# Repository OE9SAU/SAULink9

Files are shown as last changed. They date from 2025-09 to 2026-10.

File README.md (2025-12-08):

# SAULink9 - DIY interface for your analog radio

SAULink9 is a DIY project that bridges analog radios with the SVXLink Austria network or any other SVXLink networks like FM-FUNKNETZ.
It’s designed for amateur radio operators who want to flexibly connect their analog repeaters or other analog devices.

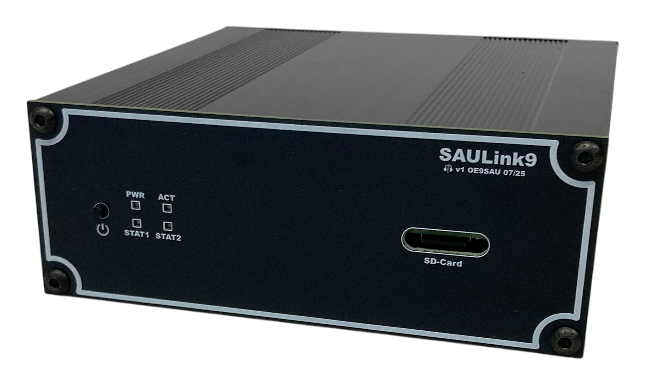
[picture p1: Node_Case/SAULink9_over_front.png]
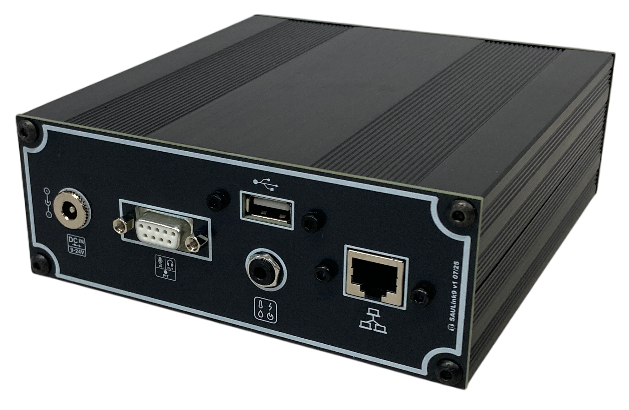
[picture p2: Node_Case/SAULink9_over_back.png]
 

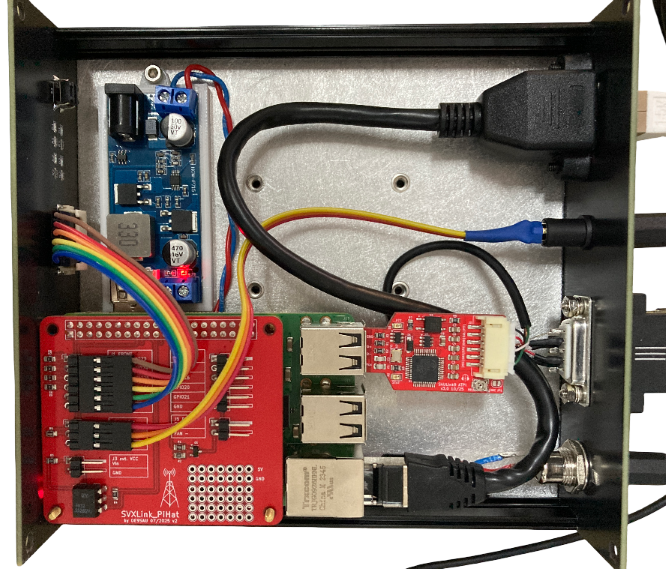
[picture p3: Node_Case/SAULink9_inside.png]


## Highlights

🔹 Base system: cost-effective Raspberry Pi 3B+

🔹 Wide-range power input (9–24 VDC) via integrated DC-DC converter

🔹[Front panel](https://github.com/OE9SAU/SAULink9/tree/main/Node_Case)
 * Start/Shutdown button
 * Status LEDs for system monitoring
 * Easy SD card front access for quick updates and maintenance
   
🔹 All key connections located on the [Back panel](https://github.com/OE9SAU/SAULink9/tree/main/Node_Case) for neat cabling
 * DC-In
 * TRX connection
 * 1-Wire temperature sensor to monitor TRX temperature
 * USB
 * Network

🔹 [PiHat for Rpi3B+](https://github.com/OE9SAU/SAULink9/tree/main/Rpi_Hat)
  * front panel connection point
  * Convenient access to 4 GPIOs (for relays or other circuits)
  * FET-controlled fan output
  * Dedicated 1-Wire port
  * External voltage detection via optocoupler
  * Extra DIY prototyping space

🔹[ATPI USB-Soundinterface with CM108](https://github.com/OE9SAU/SAULink9/tree/main/ATPI)
    
🔹 Compatible with mostly any analog TRX devices

🔹 DIY & flexible – easy to set up and adapt to your needs

🔹 Direct connection to the [SVXLink Austria Reflektor OE9XFP](http://oe9xvi.dyndns.org:46197)

🔹 Built-in EchoLink integration

🔹 Works seamlessly with other SVXLink networks such as FM-FUNKNETZ

🔹 Open source & community-driven – can be further developed together

#### SAULink9 extends the range and flexibility of your analog radios and makes getting started with the SVXLink project particularly easy.

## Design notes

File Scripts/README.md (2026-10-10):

<p align="center">
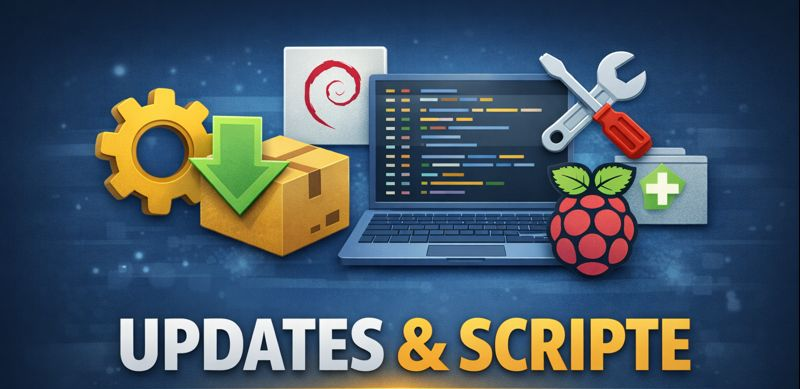
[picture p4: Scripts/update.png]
  
</p>

# Erweiterung eSM Server Monitor
Das eSM Dashboard ist im SAULink Dashboard mit einem Klick auf **Hardware Info** erreichbar.
Das Script im Ordner /eSM erweitert das bestehende eSM Dashboard um einen Temperaturgraphen zur Darstellung der CPU-Temperatur im zeitlichen Verlauf (60 Minuten).
In Verbindung mit der **FanControl** lässt sich damit gut beobachten, wie sich die CPU-Temperatur entwickelt und wann die temperaturgesteuerte Lüftersteuerung ein- bzw. ausschaltet.

## Installation
```
sudo wget -qO install-tempgraph.sh \
https://raw.githubusercontent.com/OE9SAU/SAULink9/main/Scripts/eSM/install-tempgraph.sh && \
sudo chmod +x install-tempgraph.sh && \
sudo ./install-tempgraph.sh
```

# FanControl

Temperaturgesteuerte Lüftersteuerung für SAULink auf Basis von **pigpio**.
Die FanControl überwacht die CPU-Temperatur des Raspberry Pi und steuert den angeschlossenen Lüfter automatisch anhand der festgelegten Temperaturschwellen.
Zusammen mit dem Temperaturgraphen im eSM Dashboard lässt sich das Verhalten der Lüftersteuerung einfach überwachen und nachvollziehen.

Für den Lüftereinbau muss der Gehäusedeckel modifiziert werden.

Verwendeter Lüfter: https://www.amazon.de/dp/B0DKJP347L?ref_=ppx_hzsearch_conn_dt_b_fed_asin_title_2

## Funktionen

- GPIO 18 schaltet einen Lüfter über den MosFet auf dem Rpi_Hat
- Lüfter EIN ab 65 °C
- Lüfter AUS unter 50 °C
- Hysterese verhindert Flattern
- Startet automatisch beim Booten über systemd

## Installation
```
sudo wget -qO install-fancontrol.sh \
https://raw.githubusercontent.com/OE9SAU/SAULink9/main/Scripts/fancontrol/install-fancontrol.sh && \
sudo chmod +x install-fancontrol.sh && \
sudo ./install-fancontrol.sh
```

## Standardwerte

| Parameter | Wert |
|---|---|
| GPIO | 18 |
| Einschalten | 65 °C |
| Ausschalten | 50 °C |
| Prüfintervall | 5 Sekunden |

## Dienst

Status anzeigen:

```
systemctl status fancontrol
```

Neustarten:

```
sudo systemctl restart fancontrol
```

Stoppen:

```
sudo systemctl stop fancontrol
```
---

# Update SvxLink Dashboard Ver 2.1
### Verbesserte aktualisierung der SVXReflector Activity Tabelle

-Sortierung verbessert

-Datum wird mitangezeigt

-Anzeige auf 23 Einträge erweitert

# Script herunterladen
```
wget -O /tmp/lh_update.sh \
https://raw.githubusercontent.com/OE9SAU/SAULink9/refs/heads/main/Scripts/lh_update.sh
```

# Rechte setzen
```
sudo chmod +x /tmp/lh_update.sh
```
# Script ausführen
```
sudo /tmp/lh_update.sh
```
---
# Update der Status LEDs im Frontpanel inkl.Watchdog Funktion, Schaltung unter SAULink9/Watchdog

v2.4: Statusprüfung angepasst, erkannte Authentication OK-Verbindung UP bleibt, bis tatsächlich eine Trennung/Fehlermeldung kommt

Script dient der Anpassung der Statusanzeige von SVXLink-Dienst und der Reflektor-Verbindungen über die beiden roten GPIO-LEDs im Frontpanel inkl. GPIO für Watchdog

### Statusanzeige – SVXLink (STAT LED 1 bestehend)

|SVXLink | LED-Verhalten |
|---|---|
| Dienst läuft nicht | Dauer-AN |
| Dienst läuft | Blinkend (0,5 s) |

### Statusanzeige – Reflektor (STAT LED 2 Neu)

| Reflektor Verbindung | LED-Verhalten |
|---|---|
| UP | Blinkend (0,5 s) |
| CONNECTING | Langsam blinkend |
| DOWN / ERROR | Dauer-AN |

## Installation:
```
sudo systemctl stop svxlink_service_led.service
```
### Script von GitHub laden:
```
sudo cp -a /usr/local/bin/svxlink_service_led.py \
/usr/local/bin/svxlink_service_led.py.bak 2>/dev/null || true \
&& sudo curl -fsSL https://raw.githubusercontent.com/OE9SAU/SAULink9/refs/heads/main/Scripts/svxlink_service_led.py \
-o /usr/local/bin/svxlink_service_led.py \
&& sudo chmod 755 /usr/local/bin/svxlink_service_led.py
```
### Service aktivieren:
```
sudo systemctl daemon-reload && \
sudo systemctl enable svxlink_service_led.service && \
sudo systemctl start svxlink_service_led.service
```
### Service Status:
```
sudo systemctl status svxlink_service_led.service
```
---
# Rpi System-Update:

Script führt ein normales Systemupdate (apt update + apt upgrade) durch und stellt anschließend sicher, 

dass der Apache Webserver wieder mit PrivateTmp=false läuft. Was für die Funktion von DTMF und Co benötigt wird!

## Voraussetzung: 

SAULink9 mit Debian 12 "Bookworm"

OS und Release Version anzeigen
```
. /etc/os-release && echo "Debian $VERSION_ID.$(cut -d. -f2 /etc/debian_version) ($VERSION_CODENAME)"
````

# Funktionsweise:
1. Systemupdate ausführen
2. systemd-Override für apache2 prüfen/erstellen:
/etc/systemd/system/apache2.service.d/override.conf
3. systemd neu laden
4. Apache neu starten
5. Status von PrivateTmp anzeigen

# Verwendung:
Script von GitHub laden
````
sudo curl -fsSL https://raw.githubusercontent.com/OE9SAU/SAULink9/refs/heads/main/Scripts/update-system.sh \
  -o /usr/local/sbin/update-system.sh \
  && sudo chmod 755 /usr/local/sbin/update-system.sh
````
Script ausführen
````
sudo update-system.sh
````
# Ablage:
/usr/local/sbin/update-system.sh

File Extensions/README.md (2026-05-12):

# SAULink9 Extensions @ in progess

SAULink9 is a DIY project that bridges analog radios with the SVXLink Austria network or any other SVXLink networks like FM-FUNKNETZ.
It’s designed for amateur radio operators who want to flexibly connect their analog repeaters or other analog devices.

 

## WATCHDOG

can be used to monitor the SAULink9 SVX-Service 

## TAIT-PLEXER

use two Tait Device for Repeater with and without SAULink9

## AP

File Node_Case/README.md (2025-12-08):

# SAULink9 Node Case

Front panel, back panel and base plate for aluminium housing (see partlist), fit all part´s you need to build up a SAULink9 Node for SVX- and EchoLink use.

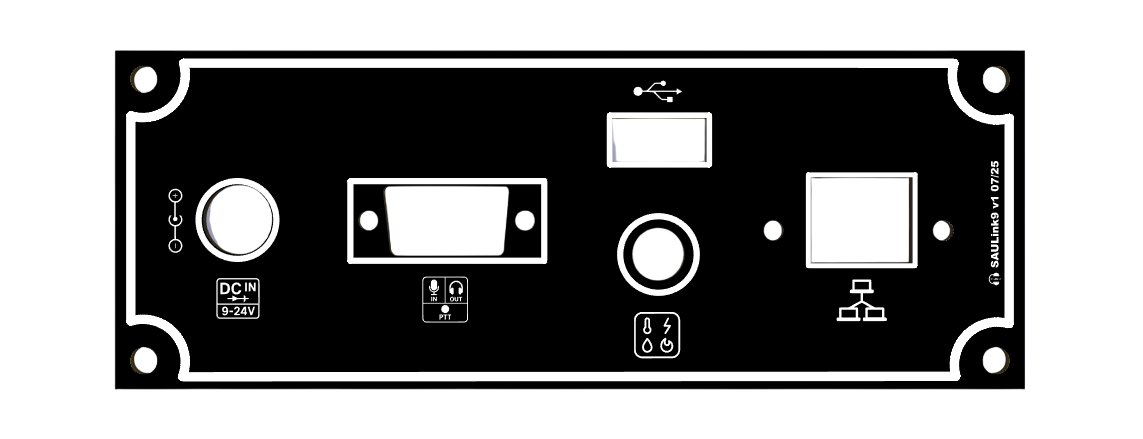
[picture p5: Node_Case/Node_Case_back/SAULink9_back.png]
Caseoverfront

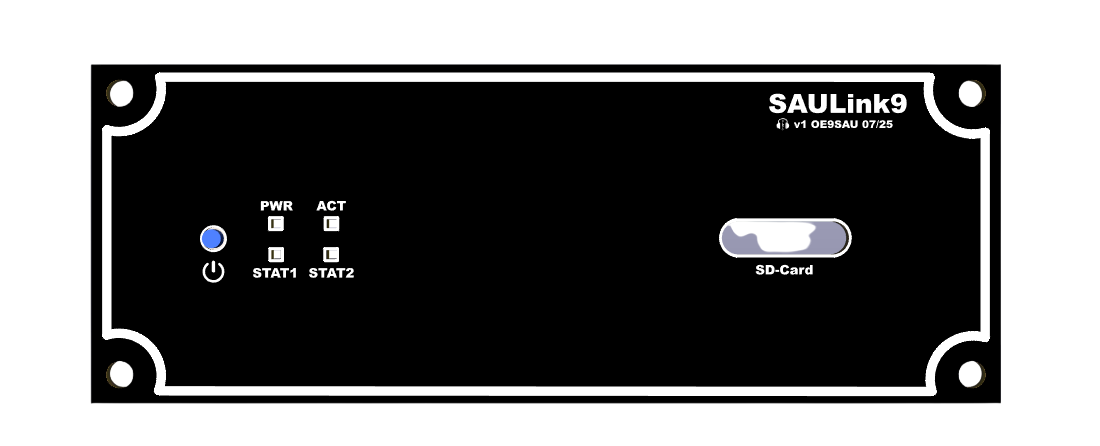
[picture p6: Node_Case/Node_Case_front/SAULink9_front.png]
Caseoverback


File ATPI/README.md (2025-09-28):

# SAULink9 ATPI

This project based on a CM108 soundchip provides an Audio and PTT (Push-to-Talk) interface to connect your analog radio.
Mainly it acts as a bridge between SAULink9 nodes and external radio hardware for any SVXLink network or any other applications.

### Features:

* Audio input/output

  * 100K potentiometer enables you to make fine tuned adjustments to the audio going in to the CM108 (GM340 etc)
    
  * Output audio levels are generally set in whichever software you're using with the ATPI

* PTT line control to GND thru optocoupler

* COS (Carrier on Squelch) input blocked by diode

* Easy integration/replacement into existing SAULink9 / SVXLink setups

* Customizing the device name with integrated EEPROM

* works with VARA

### Versions
v3.0: like v2.0 with EEPROM for Device name informations

v2.0: shorter version without 1:1 transformer

v1.1: like v1.0 footprint D1 changed to SOD-123

v1.0: with 1:1 transformer -> Audio level to low

### Note
all versions must be ordered in 1.2mm PCB thickness

all versions must be glued together with the empty board version, ordered as well with 1.2mm PCB thicknes, to achieve the USB connector thickness of around 2.5mm

v3.0
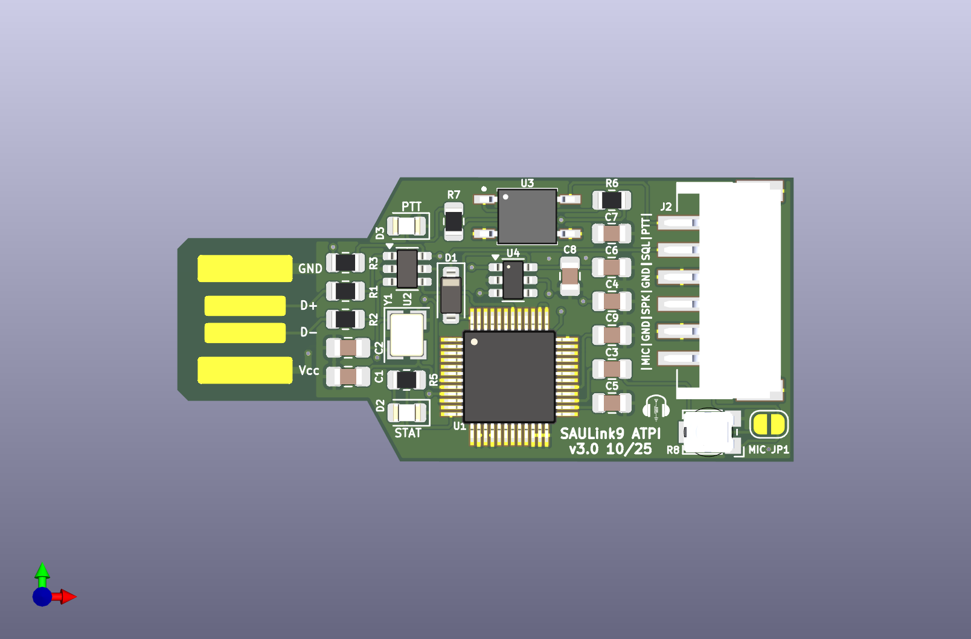
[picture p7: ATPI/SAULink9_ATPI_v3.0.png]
ATPI


v2.0
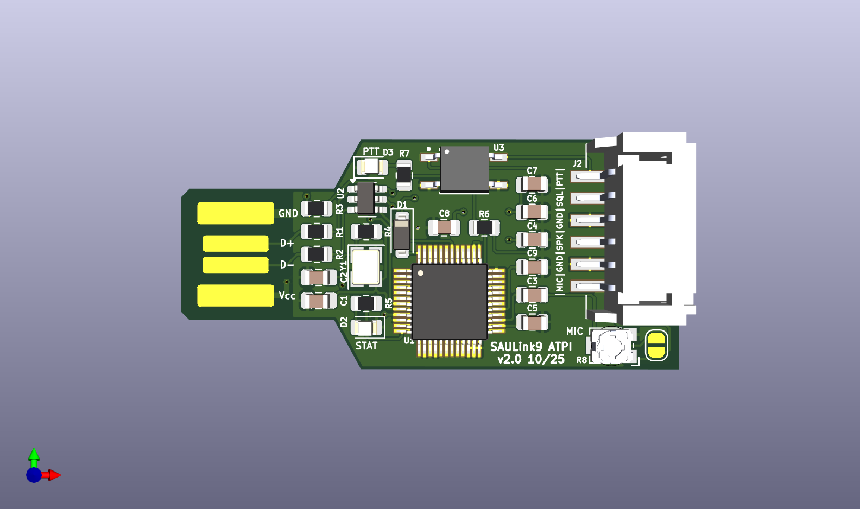
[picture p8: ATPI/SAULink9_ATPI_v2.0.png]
ATPI


v1.1
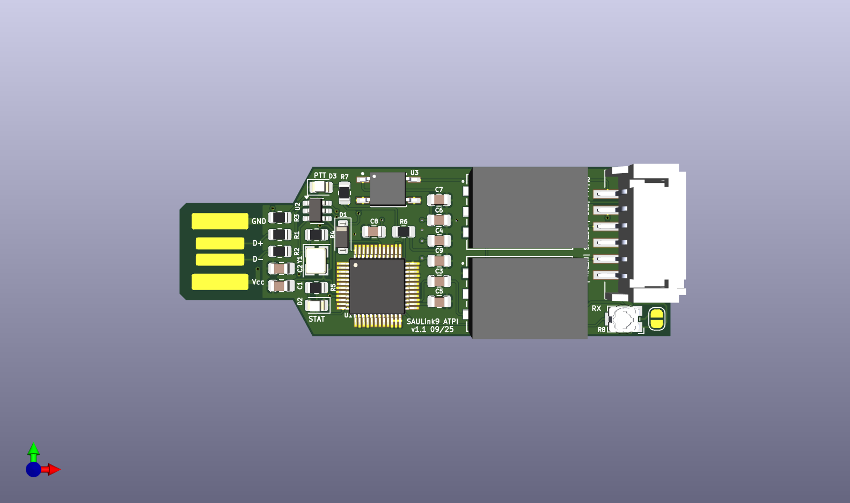
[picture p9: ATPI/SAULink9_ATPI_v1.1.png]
ATPI


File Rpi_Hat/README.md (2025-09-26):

# SAULink9 RPiHat

PiHat for Rpi3B+, give space to some GPIOs and connection point to the SAULink9 front panel

## Highlights
  * front panel connection point
  * Convenient access to 4 GPIOs (for relays or other circuits)
  * FET-controlled fan output
  * Dedicated 1-Wire port
  * External voltage detection via optocoupler
  * Extra DIY prototyping space

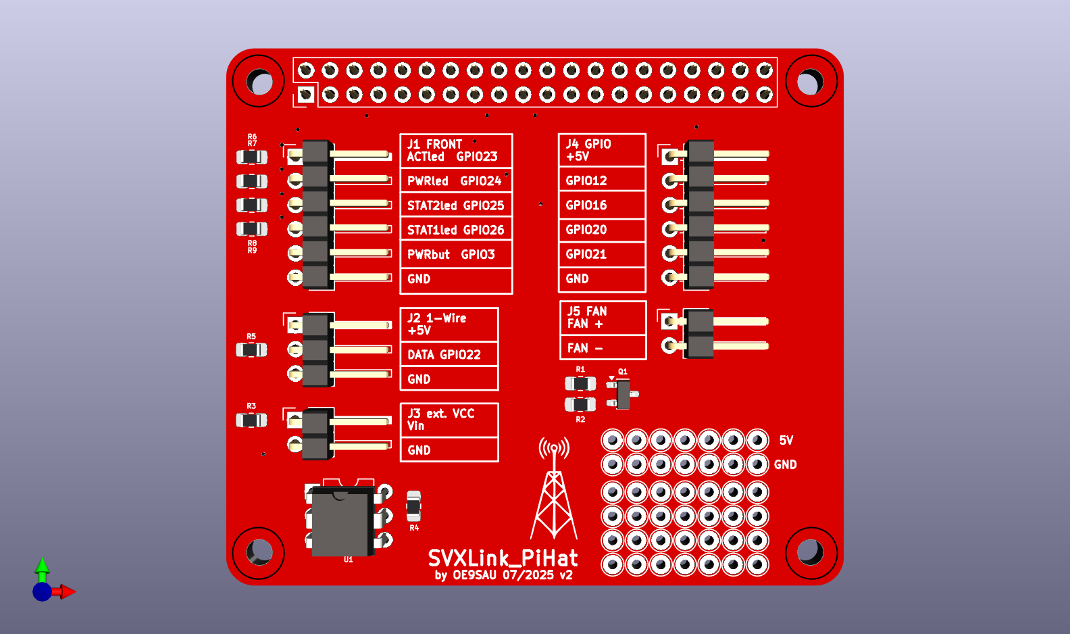
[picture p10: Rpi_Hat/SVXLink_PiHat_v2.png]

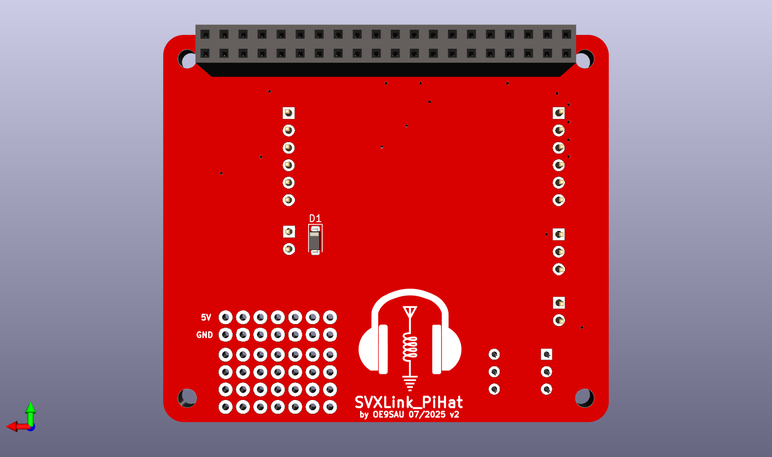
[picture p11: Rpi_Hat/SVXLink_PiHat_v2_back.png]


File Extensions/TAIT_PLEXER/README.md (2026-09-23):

## SAULink9 TAIT-PLEXER

In case of problems like no reflector connection or SAULink9 down, SAULink9 Watchdog (Extensions/WATCHDOG) sets the TAIT-PLEXER 

to LOW and both TAIT device are acting as local fm-repeater

v1.0 Testdesign

v1.1 changed pinout v1.0 by handwiring for current TAIT pinout config

v2.0 changed pinout for current TAIT pinout config

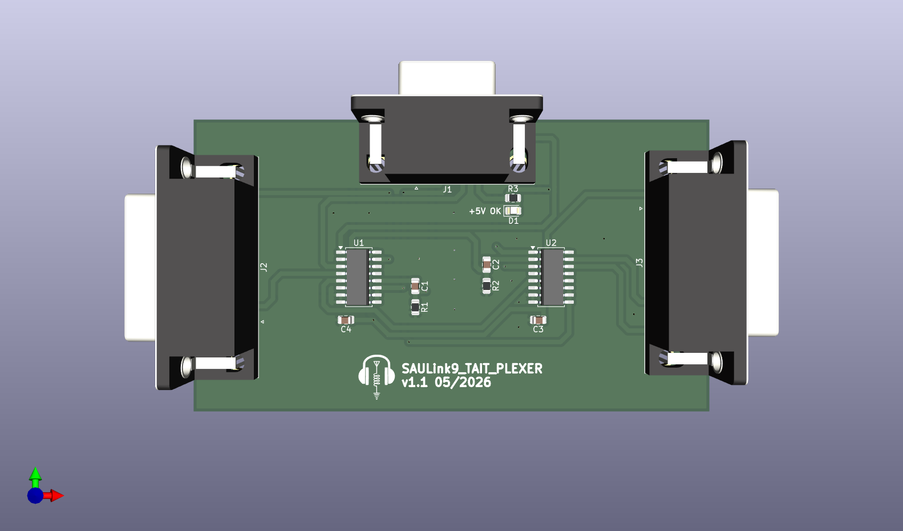
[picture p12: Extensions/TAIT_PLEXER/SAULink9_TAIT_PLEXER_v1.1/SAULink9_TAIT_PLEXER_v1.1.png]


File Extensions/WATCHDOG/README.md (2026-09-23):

## SAULink9 Watchdog v1.1

The watchdog timer is repeatedly started by a trigger. If the trigger is missing, the timer with 33sec runs down and then the output switch to ...

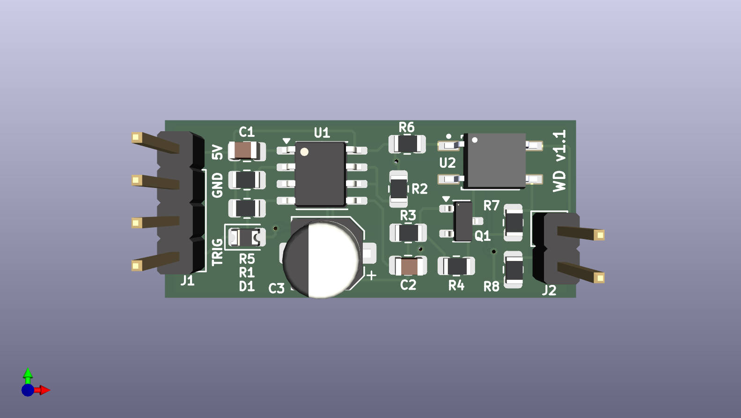
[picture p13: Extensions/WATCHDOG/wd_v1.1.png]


v1.1: Add R7 & R8 to define PULLUP or PULLDOWN, without R7 & R8 acting potentialfree

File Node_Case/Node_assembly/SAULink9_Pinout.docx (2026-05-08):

1-Wire jack socket

1 | GND
2 | 5V
3 | Data
4 | ------

1-Wire jack plug

5V

Data

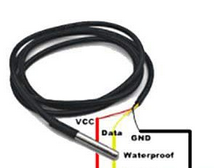
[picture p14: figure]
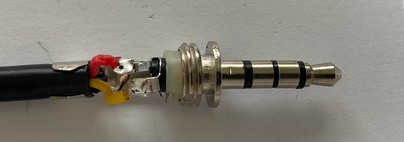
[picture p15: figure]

Sub-D 9pol (Blick von hinten auf die Buchse)

Sub-D | Code | | Sub-D Kabel zu TRX
1 | shield | GND | red
2 | black | PTT, Aktiv LOW | green
4 | red | CTCSS/SQL | lila
7 | white | Output = TX Audio | white
9 | green | Input = RX Audio | black

Amazon Soundinterface

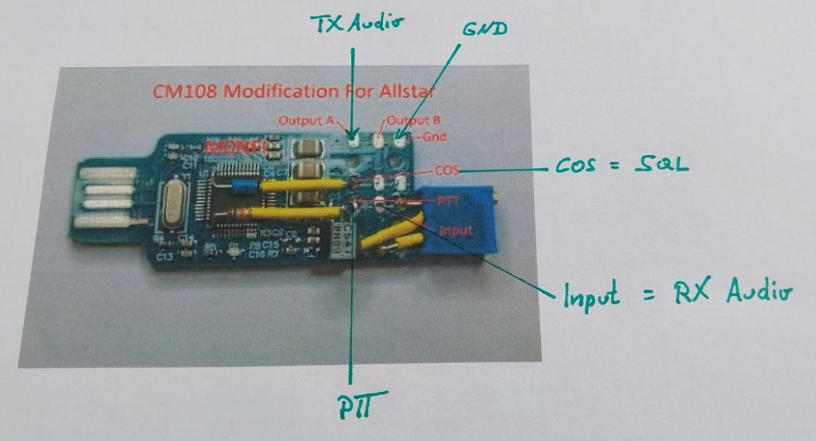
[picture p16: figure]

ATPI

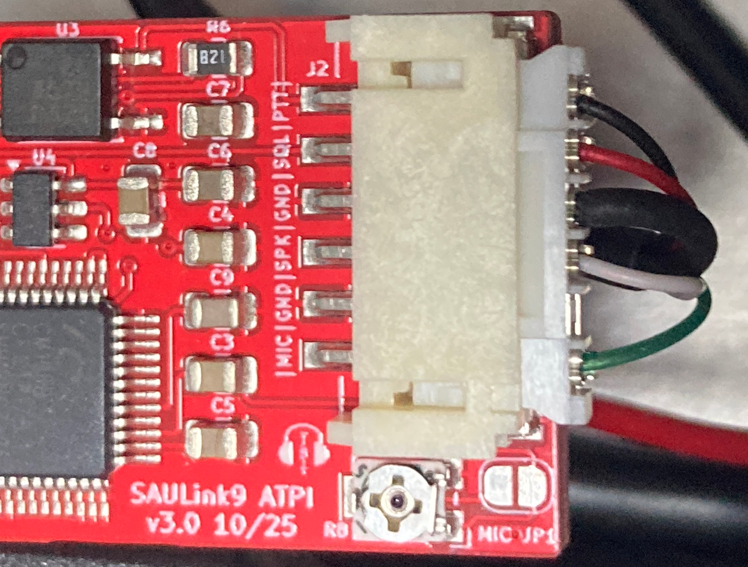
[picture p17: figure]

GM340 Simplex

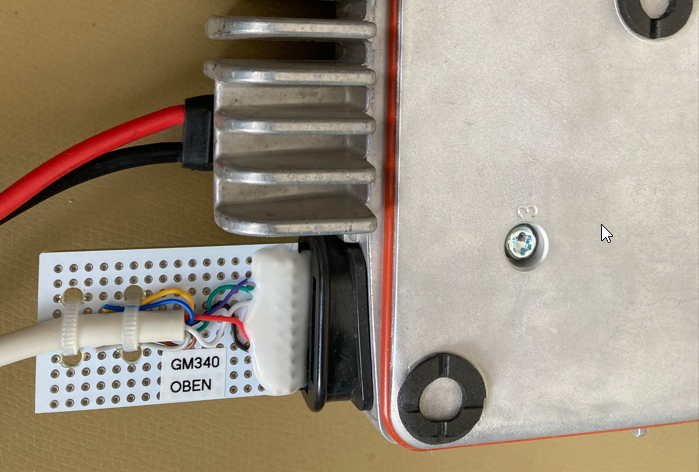
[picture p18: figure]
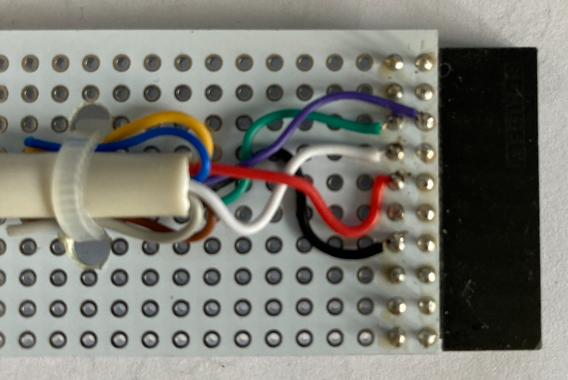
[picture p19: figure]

GM340 Repeater (Nur für Repeater Mode, NICHT Simplex)

Pin | SUB-D Kabel | Kabel zu RX (Amz) | Kabel zu TX (Amz) | | Kabel zu RX (Reichelt) | Kabel zu TX (Reichelt)
1 | GND | red | red | | braun | braun
2 | PTT, Aktiv LOW | | green | | | rot
4 | CTCSS/SQL | lila | | | gelb
5 | 12V | brown | brown | | grün | grün
7 | Output = TX Audio | | white | | | lila
9 | Input = RX Audio | black | | | weiss

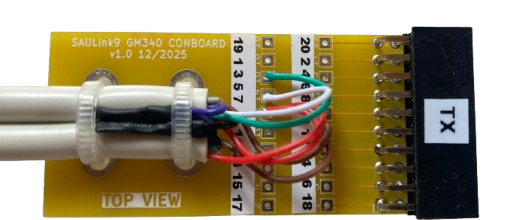
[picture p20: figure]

Amz: schwarz u. lila verlängern für RX (braun für 12V)

Reichelt: gelb u. weiss verlängern für RX (grün für 12V)

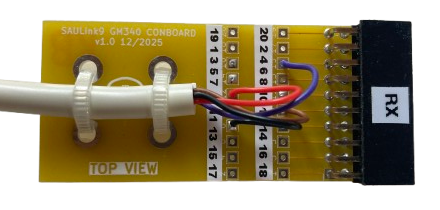
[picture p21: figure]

ATPI-Settings

alsamixer

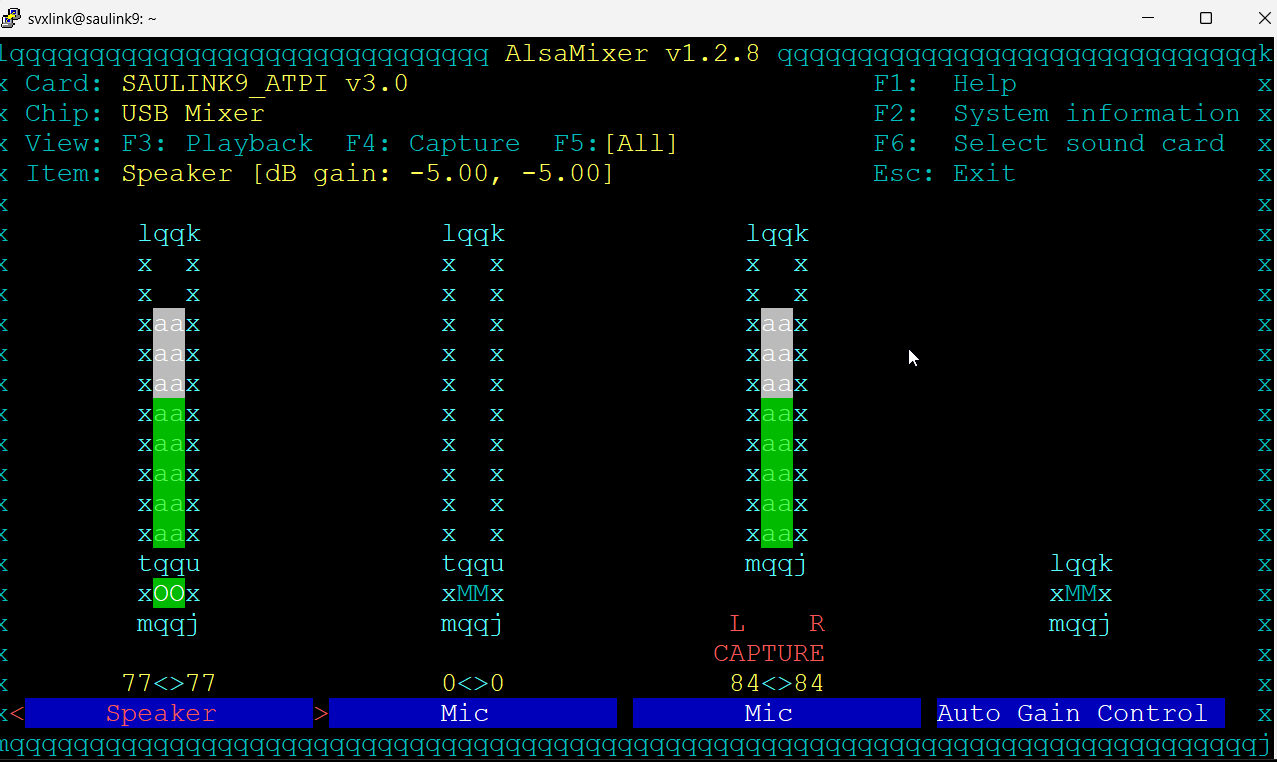
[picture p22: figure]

Nach Änderungen: sudo alsactl store

sudo arecord -D hw:0 -f S16_LE -c2 -r48000 -V mono /dev/null

SAULink9 Pinout & Settings

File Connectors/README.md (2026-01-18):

# Easy connect a GM340

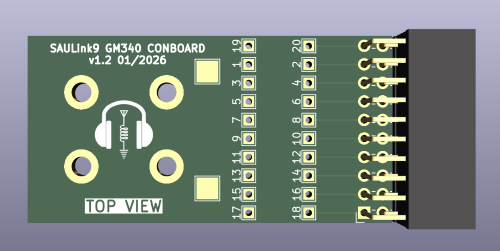
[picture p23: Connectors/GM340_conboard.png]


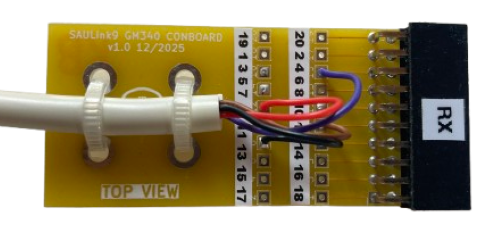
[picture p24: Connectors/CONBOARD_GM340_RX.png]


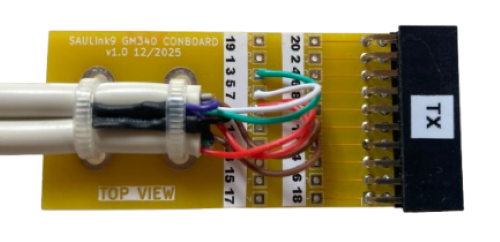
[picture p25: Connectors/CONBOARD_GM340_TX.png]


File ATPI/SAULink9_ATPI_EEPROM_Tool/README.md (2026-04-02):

# CM108_EEPROM_Utility

A Python tool for accessing the external configuration EEPROM via the ASIC's custom HID endpoint. by https://github.com/islandcontroller

## Usage

Start SAULink_ATPI_EEPROM_Tool_v0.6.py, the script will do the rest.
To program a configuration use .......Rpi.yaml

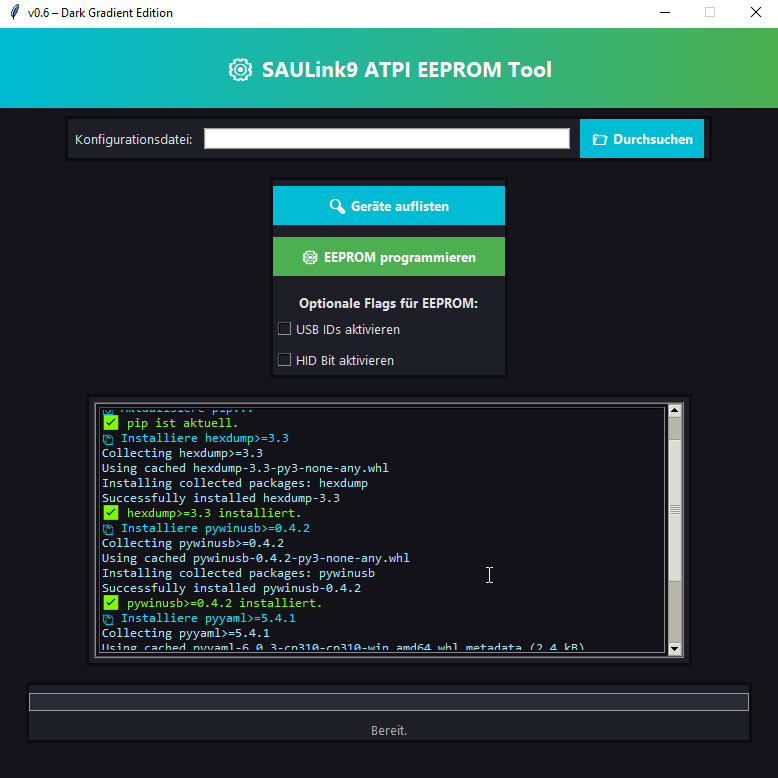
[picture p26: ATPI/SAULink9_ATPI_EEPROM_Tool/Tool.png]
GUI


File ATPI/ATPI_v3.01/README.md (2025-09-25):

## Cheap TRX Interace for SAULink9 Node's or any other hamradio soundapplication

### Features:

* Audio IN
* Audio Out
* PTT OUT
* SQL IN

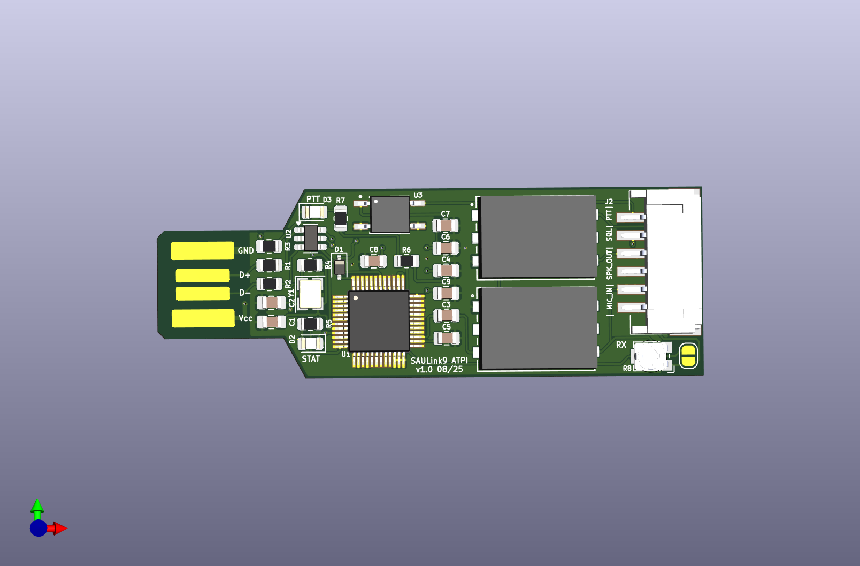
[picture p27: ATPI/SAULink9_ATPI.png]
ATPI


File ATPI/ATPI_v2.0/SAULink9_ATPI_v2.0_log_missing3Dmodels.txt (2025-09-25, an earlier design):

Can not find model defined with enviroment variable:
${KICAD8_3DMODEL_DIR}/Capacitor_SMD.3dshapes/C_0805_2012Metric.wrl
Can not find model defined with enviroment variable:
${KICAD8_3DMODEL_DIR}/Resistor_SMD.3dshapes/R_0805_2012Metric.wrl
Can not find model defined with enviroment variable:
${KICAD8_3DMODEL_DIR}/Resistor_SMD.3dshapes/R_0805_2012Metric.wrl
Can not find model defined with enviroment variable:
${KICAD8_3DMODEL_DIR}/Resistor_SMD.3dshapes/R_0805_2012Metric.wrl
Can not find model defined with enviroment variable:
${KICAD8_3DMODEL_DIR}/Capacitor_SMD.3dshapes/C_0805_2012Metric.wrl
Can not find model defined with enviroment variable:
${KICAD8_3DMODEL_DIR}/Resistor_SMD.3dshapes/R_0805_2012Metric.wrl
Can not find model defined with enviroment variable:
${KICAD8_3DMODEL_DIR}/Capacitor_SMD.3dshapes/C_0805_2012Metric.wrl
Can not find model defined with enviroment variable:
${KICAD8_3DMODEL_DIR}/Capacitor_SMD.3dshapes/C_0805_2012Metric.wrl
Can not find model defined with enviroment variable:
${KICAD8_3DMODEL_DIR}/LED_SMD.3dshapes/LED_0805_2012Metric.wrl
Can not find model defined with enviroment variable:
${KICAD8_3DMODEL_DIR}/Resistor_SMD.3dshapes/R_0805_2012Metric.wrl
Can not find model defined with enviroment variable:
${KICAD8_3DMODEL_DIR}/Capacitor_SMD.3dshapes/C_0805_2012Metric.wrl
Can not find model defined with enviroment variable:
${KICAD8_3DMODEL_DIR}/Capacitor_SMD.3dshapes/C_0805_2012Metric.wrl
Can not find model defined with enviroment variable:
${KICAD8_3DMODEL_DIR}/LED_SMD.3dshapes/LED_0805_2012Metric.wrl
Can not find model defined with enviroment variable:
${KICAD8_3DMODEL_DIR}/Resistor_SMD.3dshapes/R_0805_2012Metric.wrl
Can not find model defined with enviroment variable:
${KICAD8_3DMODEL_DIR}/Capacitor_SMD.3dshapes/C_0805_2012Metric.wrl
Can not find model defined with enviroment variable:
${KICAD8_3DMODEL_DIR}/Crystal.3dshapes/Crystal_SMD_3225-4Pin_3.2x2.5mm.wrl
Can not find model defined with enviroment variable:
${KICAD8_3DMODEL_DIR}/Capacitor_SMD.3dshapes/C_0805_2012Metric.wrl
Can not find model defined with enviroment variable:
${KICAD8_3DMODEL_DIR}/Capacitor_SMD.3dshapes/C_0805_2012Metric.wrl
Can not find model defined with enviroment variable:
${KICAD8_3DMODEL_DIR}/Package_TO_SOT_SMD.3dshapes/SOT-23-6.wrl
Can not find model defined with enviroment variable:
${KICAD8_3DMODEL_DIR}/Diode_SMD.3dshapes/D_SOD-123.wrl
[('C5', '${KICAD8_3DMODEL_DIR}/Capacitor_SMD.3dshapes/C_0805_2012Metric.wrl'), ('R3', '${KICAD8_3DMODEL_DIR}/Resistor_SMD.3dshapes/R_0805_2012Metric.wrl'), ('R6', '${KICAD8_3DMODEL_DIR}/Resistor_SMD.3dshapes/R_0805_2012Metric.wrl'), ('R2', '${KICAD8_3DMODEL_DIR}/Resistor_SMD.3dshapes/R_0805_2012Metric.wrl'), ('C8', '${KICAD8_3DMODEL_DIR}/Capacitor_SMD.3dshapes/C_0805_2012Metric.wrl'), ('R7', '${KICAD8_3DMODEL_DIR}/Resistor_SMD.3dshapes/R_0805_2012Metric.wrl'), ('C4', '${KICAD8_3DMODEL_DIR}/Capacitor_SMD.3dshapes/C_0805_2012Metric.wrl'), ('C2', '${KICAD8_3DMODEL_DIR}/Capacitor_SMD.3dshapes/C_0805_2012Metric.wrl'), ('D2', '${KICAD8_3DMODEL_DIR}/LED_SMD.3dshapes/LED_0805_2012Metric.wrl'), ('R5', '${KICAD8_3DMODEL_DIR}/Resistor_SMD.3dshapes/R_0805_2012Metric.wrl'), ('C1', '${KICAD8_3DMODEL_DIR}/Capacitor_SMD.3dshapes/C_0805_2012Metric.wrl'), ('C9', '${KICAD8_3DMODEL_DIR}/Capacitor_SMD.3dshapes/C_0805_2012Metric.wrl'), ('D3', '${KICAD8_3DMODEL_DIR}/LED_SMD.3dshapes/LED_0805_2012Metric.wrl'), ('R1', '${KICAD8_3DMODEL_DIR}/Resistor_SMD.3dshapes/R_0805_2012Metric.wrl'), ('C7', '${KICAD8_3DMODEL_DIR}/Capacitor_SMD.3dshapes/C_0805_2012Metric.wrl'), ('Y1', '${KICAD8_3DMODEL_DIR}/Crystal.3dshapes/Crystal_SMD_3225-4Pin_3.2x2.5mm.wrl'), ('C6', '${KICAD8_3DMODEL_DIR}/Capacitor_SMD.3dshapes/C_0805_2012Metric.wrl'), ('C3', '${KICAD8_3DMODEL_DIR}/Capacitor_SMD.3dshapes/C_0805_2012Metric.wrl'), ('U2', '${KICAD8_3DMODEL_DIR}/Package_TO_SOT_SMD.3dshapes/SOT-23-6.wrl'), ('D1', '${KICAD8_3DMODEL_DIR}/Diode_SMD.3dshapes/D_SOD-123.wrl')]

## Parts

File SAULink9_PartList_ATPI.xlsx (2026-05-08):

Teile | Preis | Amazon
Alu Gehäuse 150*145*54 | EUR 22.58 | https://www.amazon.de/dp/B08DG2X7K5?ref=ppx_yo2ov_dt_b_fed_asin_title
Base plate for case |  | DIY
Front Panel | EUR 2.50 | https://github.com/OE9SAU/SAULink9/tree/main/Node_Case
Back Panel | EUR 2.50 | https://github.com/OE9SAU/SAULink9/tree/main/Node_Case
SAULINK9_ATPI | EUR 2.50 | https://github.com/OE9SAU/SAULink9/tree/main/ATPI
SVXLink Pi Hat | EUR 2.50 | https://github.com/OE9SAU/SAULink9/tree/main/Rpi_Hat
DC-DC 5V/5A | EUR 3.20 | https://www.amazon.de/dp/B0D1K83XRZ?ref=ppx_yo2ov_dt_b_fed_asin_title
RJ45 plug to socket (30cm) | EUR 6.24 | https://www.amazon.de/dp/B01EF000NM?ref=ppx_yo2ov_dt_b_fed_asin_title
D-Sub Kabel Ende offen 1m | EUR 6.00 | https://www.amazon.de/gp/product/B07TYN693Y/ref=ox_sc_act_title_1?smid=A3JWKAKR8XB7XF&psc=1
Klinkeneinbaubuchse | EUR 0.67 | https://www.amazon.de/dp/B09NDP25YY?ref=ppx_yo2ov_dt_b_fed_asin_title
USB Pigtail | EUR 1.41 | https://www.amazon.de/dp/B0D2VMSMGC?ref=ppx_yo2ov_dt_b_fed_asin_title&th=1
SD Card (16gb) | EUR 7.00 | https://www.amazon.de/gp/product/B08KSSX9PH/ref=ewc_pr_img_1?smid=A1G2FC5CI8M2YB&th=1
USB plug to socket | EUR 3.50 | https://de.aliexpress.com/item/1005005555653710.html?mp=1
 |  | Reichelt
Rpi3b+ | EUR 38.22 | RASPBERRY PI 3B+
DC Einbaubuchse | EUR 1.21 | HEBLM 25
DC Stecker | EUR 0.23 | HS 25-9
D-Sub 9pol | EUR 0.18 | D-SUB BU 09
D-Sub Schraubsverriegelungssatz | EUR 1.16 | BKL 10120291
JST - Buchsengehäuse, RM 2,5 mm, 1x6 polig, gew. - XH | EUR 0.05 | JST XH6P SM4
Taster, 1 Schließer (NO) | EUR 0.50
Kleinmaterial SMD Widerstände, Abstandshalter, Drähte, usw. | EUR 10.00
Parts for ATPI from LCSC | EUR 6.00
 | EUR 118.15

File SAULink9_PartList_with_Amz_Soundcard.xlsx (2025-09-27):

Teile | Preis | Amazon
Alu Gehäuse 150*145*54 | EUR 20.56 | https://www.amazon.de/dp/B08DG2X7K5?ref=ppx_yo2ov_dt_b_fed_asin_title
Base plate for case |  | DIY
Front Panel | EUR 2.50 | https://github.com/OE9SAU/SAULink9/tree/main/Node_Case
Back Panel | EUR 2.50 | https://github.com/OE9SAU/SAULink9/tree/main/Node_Case
SVXLink Pi Hat | EUR 2.50 | https://github.com/OE9SAU/SAULink9/tree/main/Rpi_Hat
DC-DC 5V/5A | EUR 3.20 | https://www.amazon.de/dp/B0D1K83XRZ?ref=ppx_yo2ov_dt_b_fed_asin_title
USB-Soundcard | EUR 7.50 | https://www.amazon.de/dp/B087V62BYH?ref=ppx_yo2ov_dt_b_fed_asin_title
RJ45 plug to socket (30cm) | EUR 6.24 | https://www.amazon.de/dp/B01EF000NM?ref=ppx_yo2ov_dt_b_fed_asin_title
D-Sub Kabel Ende offen 1m | EUR 6.00 | https://www.amazon.de/gp/product/B07TYN693Y/ref=ox_sc_act_title_1?smid=A3JWKAKR8XB7XF&psc=1
Klinkeneinbaubuchse | EUR 0.67 | https://www.amazon.de/dp/B09NDP25YY?ref=ppx_yo2ov_dt_b_fed_asin_title
USB Pigtail | EUR 1.41 | https://www.amazon.de/dp/B0D2VMSMGC?ref=ppx_yo2ov_dt_b_fed_asin_title&th=1
SD Card (16gb) | EUR 7.00 | https://www.amazon.de/gp/product/B08KSSX9PH/ref=ewc_pr_img_1?smid=A1G2FC5CI8M2YB&th=1
USB plug to socket | EUR 3.00 | https://de.aliexpress.com/item/1005005555653710.html?mp=1
Rpi3b+ | EUR 38.22 | Reichelt
DC Einbaubuchse | EUR 1.21 | RASPBERRY PI 3B+
DC Stecker | EUR 0.23 | HEBLM 25
D-Sub 9pol | EUR 0.18 | HS 25-9
D-Sub Schraubsverriegelungssatz | EUR 1.16 | D-SUB BU 09
Schottkydiode, 30 V, 0,2 A, DO-35 | EUR 0.05 | BKL 10120291
Bipolartransistor, NPN, 45V, 0,1A, 0,5W, TO-92 LF | EUR 0.07 | BAT 43 STM
Widerstand, Metallschicht, 4,70 kOhm, 0207, 0,6 W, 1% | EUR 0.07 | BC547CTA
Präzisionspotentiometer, 25 Gänge, liegend, 50 kOhm (nur bei Motorola) | EUR 0.24 | METALL 4,70K
JST - Buchsengehäuse, RM 2,5 mm, 1x6 polig, gew. - XH | EUR 0.45 | 64P-50K
Taster, SMD, 1 Schließer (NO) | EUR 0.33 | JST XH6P SM4
Kleinmaterial SMD Widerstände, Abstandshalter, Drähte, usw. | EUR 10.00 | OMR B3FS-1012P
 | EUR 115.29

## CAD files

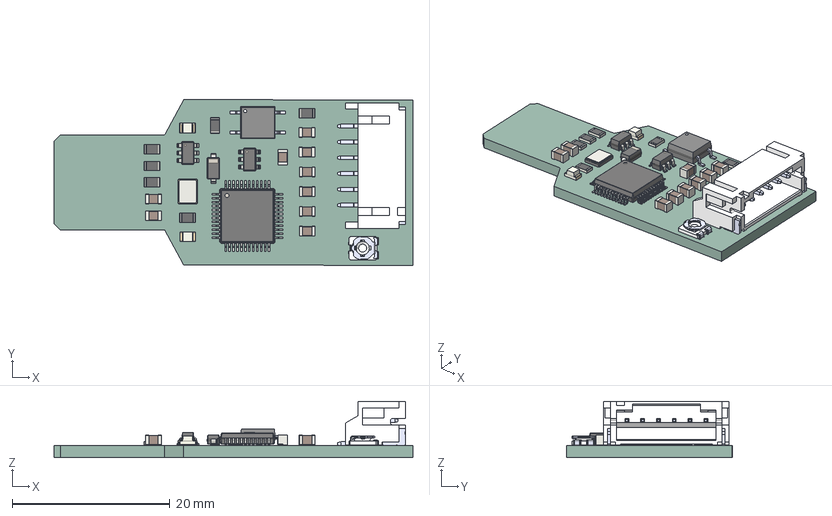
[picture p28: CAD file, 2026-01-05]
ATPI/ATPI_v3.01/SAULink9_ATPI_v3.01.step
45.5 x 21.0 x 7.10 mm
C_0805_2012Metric x 9
R_0805_2012Metric x 6
SOT-23-6 x 2
TC33X-2-103E
LED_0805_2012Metric x 2
SxB-PH-SM4-TB white_6
EL357N-G--3DModel-STEP-510211
LQFP-48_7x7mm_P0.5mm
Crystal_SMD_3225-4Pin_3.2x2.5mm
D_SOD-123
SAULink9_ATPI_v3.0_PCB

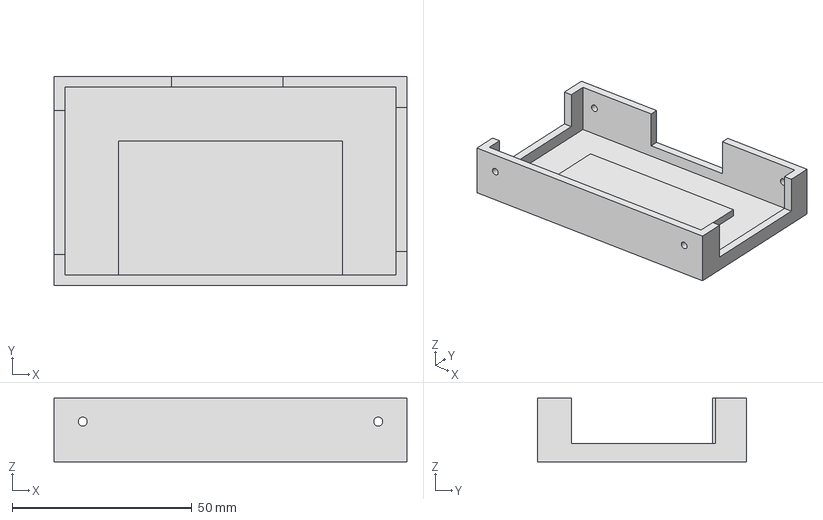
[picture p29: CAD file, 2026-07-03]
Extensions/TAIT_PLEXER/3d_case/unterteil.stp
98.2 x 58.2 x 17.7 mm

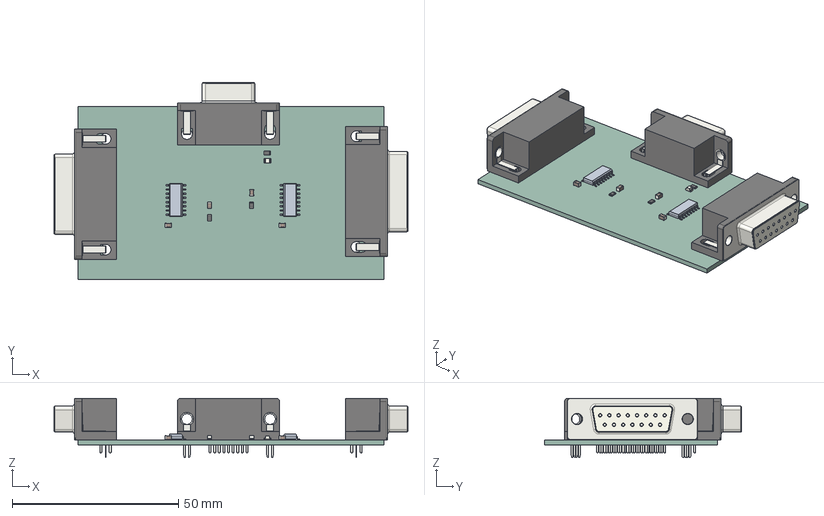
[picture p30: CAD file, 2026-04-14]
Extensions/TAIT_PLEXER/SAULink9_TAIT_PLEXER_v2.0/SAULink9_TAIT_PLEXER_v2.0.step
106.5 x 59.3 x 17.9 mm
C_0805_2012Metric x 4
SAULink9_TAIT_PLEXER 1.2 x 2
LED_0805_2012Metric
R_0805_2012Metric x 3
DSUB-15_Socket_Horizontal_P2.77x2.84mm_EdgePinOffset7.70mm_Housed_ MountingHolesOffset9.12mm x 2
DSUB-9_Socket_Horizontal_P2.77x2.84mm_EdgePinOffset7.70mm_Housed_ MountingHolesOffset9.12mm
SAULink9_TAIT_PLEXER_PCB

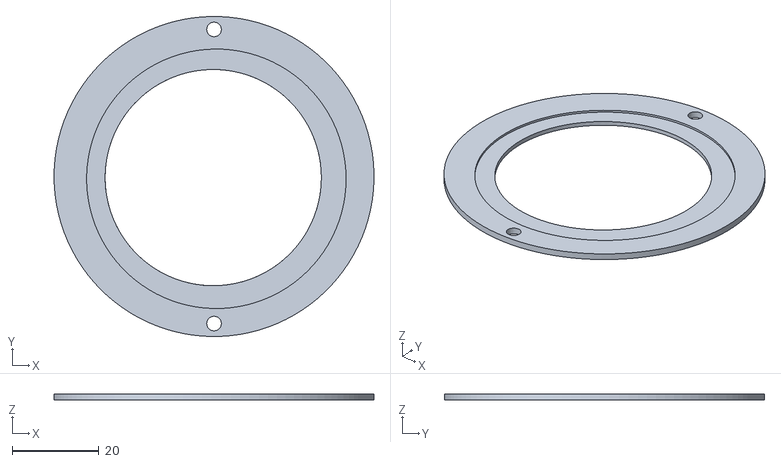
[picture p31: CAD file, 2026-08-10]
Node_Case/3d_stuff/Abdeckung_Lüfter_oben_v2.stl
74.0 x 74.0 x 1.50

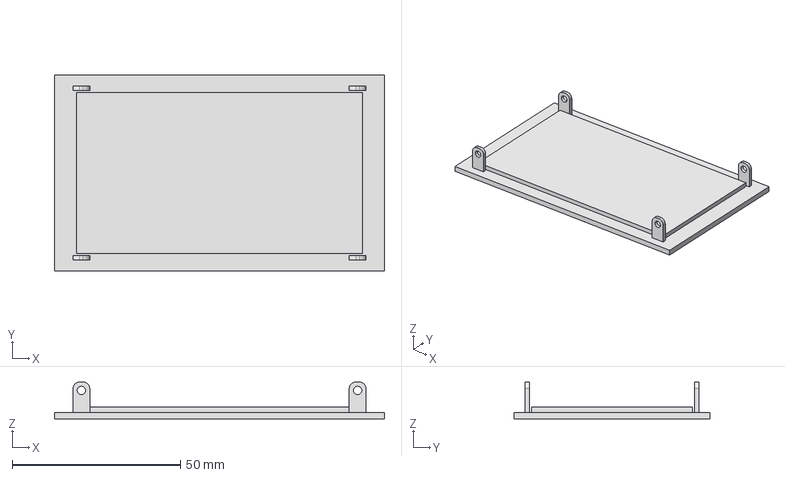
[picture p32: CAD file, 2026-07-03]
Extensions/TAIT_PLEXER/3d_case/deckel.stp
98.2 x 58.2 x 11.0 mm

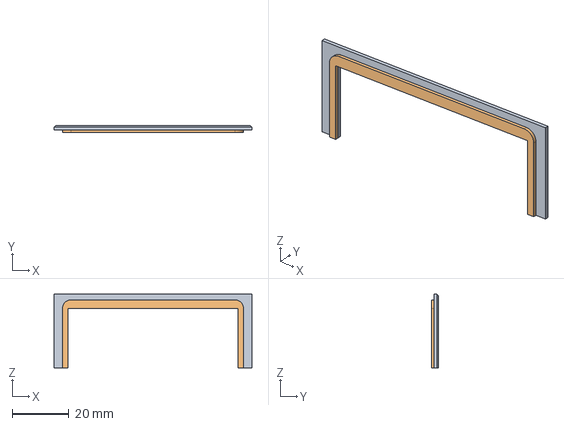
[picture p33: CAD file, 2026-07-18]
Node_Case/3d_stuff/Luftaustrittsrahmen.FCStd
70.0 x 2.40 x 26.0 mm

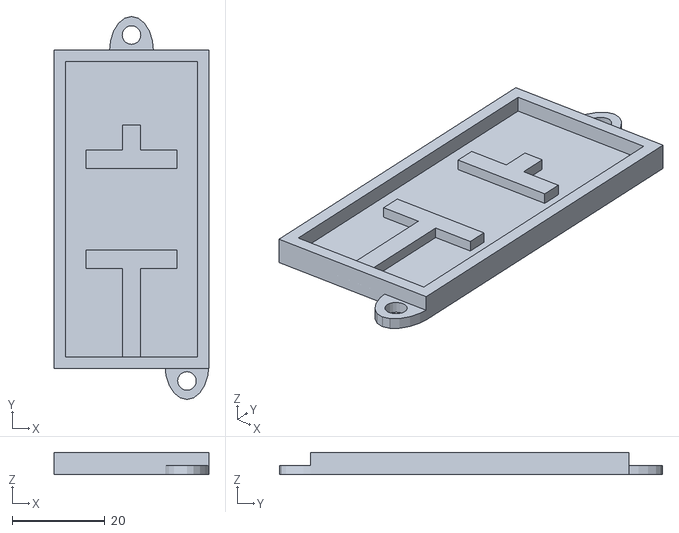
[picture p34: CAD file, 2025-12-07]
Node_Case/3d_stuff/DC-DC_Buck_mount.stl
33.3 x 82.5 x 4.80

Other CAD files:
Node_Case/3d_stuff/Luftaustrittsrahmen.stl

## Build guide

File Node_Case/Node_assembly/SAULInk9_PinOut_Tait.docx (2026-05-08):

SAULink9

Pin | SUB-D Kabel | Kabel zu RX | Kabel zu TX
1 | GND | rot | rot
2 | PTT, Aktiv LOW | | grün
4 | CTCSS/SQL | lila
5
7 | Output = TX Audio | | weiss
9 | Input = RX Audio | schwarz

RX-Sub-D 15pol (Stecker)

1 | | Amazon Kabel
2
3
4
5
6
7
8
9 | lila | SQL /Busy Status
10
11
12
13 | schwarz | AUD_TAP_OUT
14
15 | rot | GND

TX-Sub-D 15pol (Stecker)

1 | | Amazon Kabel
2
3
4
5
6
7 | weiss | AUD_TAP_IN
8
9
10
11
12 | grün | PTT
13
14
15 | rot | GND

schwarz u. lila verlängern für RX

SIMPLEX:
Sub-D 15pol (Stecker)

| Amz Kabel | Reichelt Kabel
1
2
3
4
5
6
7 | weiss | lila | AUD_TAP_IN
8
9 | lila | gelb | SQL /Busy Status
10
11
12 | grün | rot | PTT
13 | schwarz | weiss | AUD_TAP_OUT
14
15 | rot | braun | GND

Tait SVXLink

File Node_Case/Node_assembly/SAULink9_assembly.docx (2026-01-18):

1) mount DC-DC power supply to baseplate

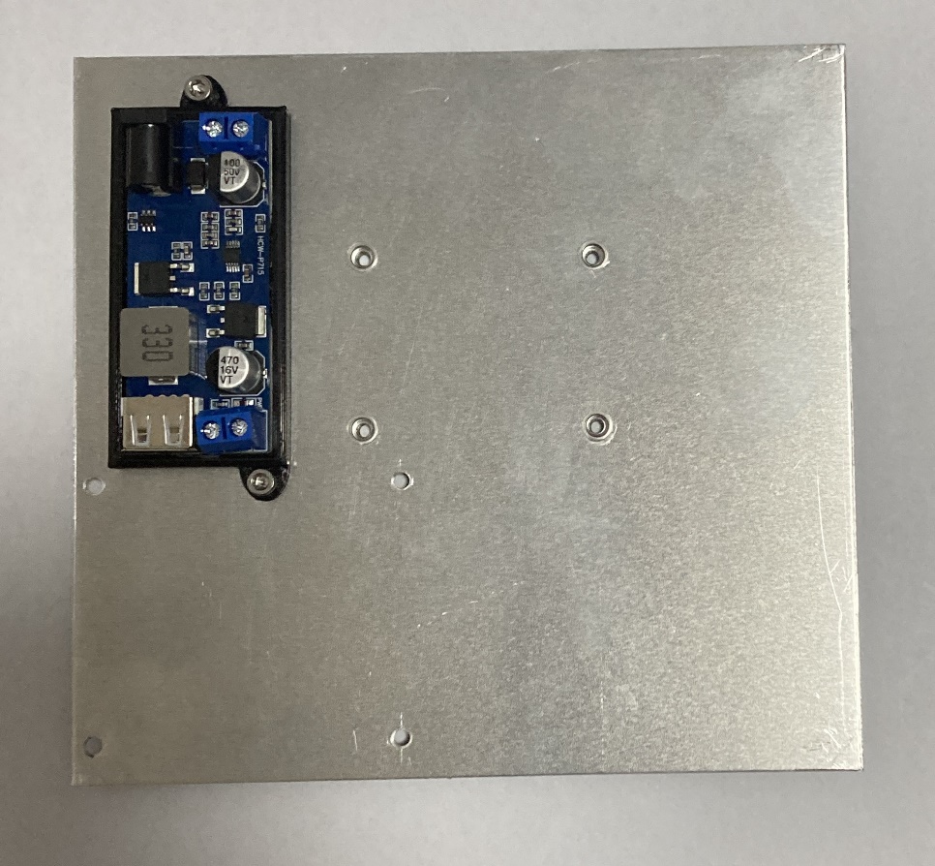
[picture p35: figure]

2) solder USB pigtail to RPI

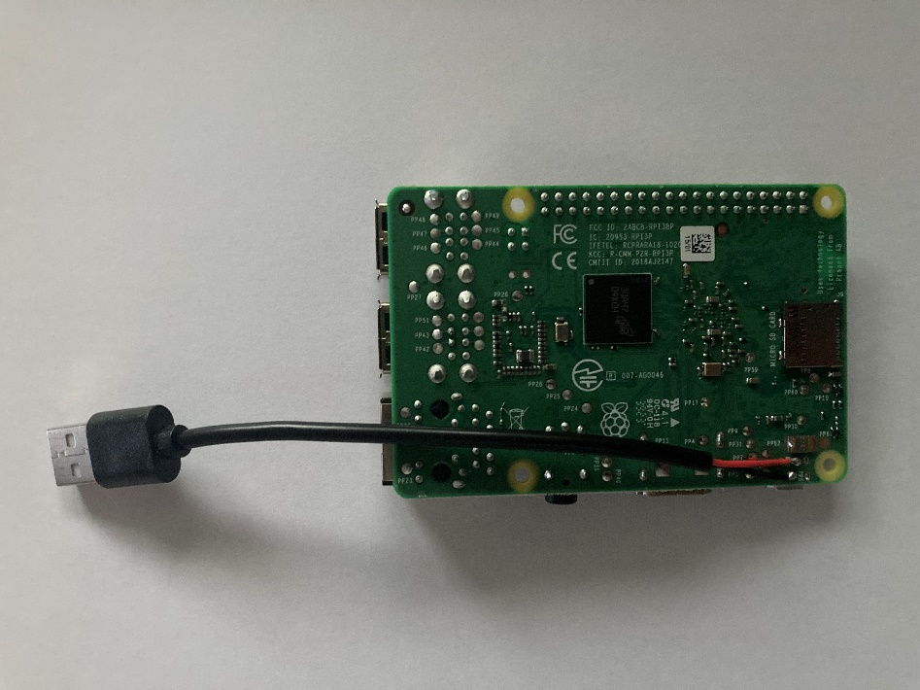
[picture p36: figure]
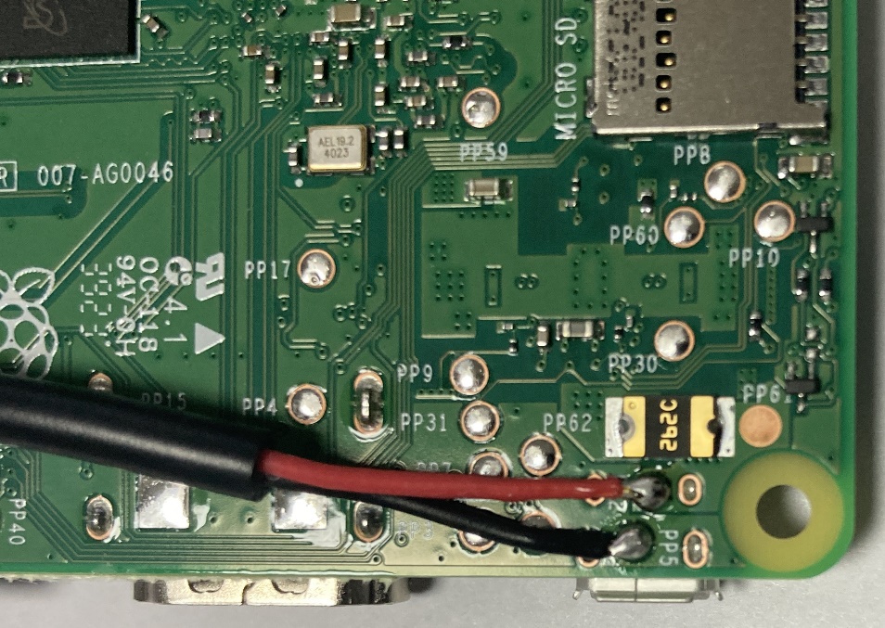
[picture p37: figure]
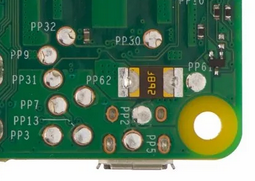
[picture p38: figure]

PP5 = GND (black) // PP2 = 5V (red)

3) Mount RPI with spacer to base plate

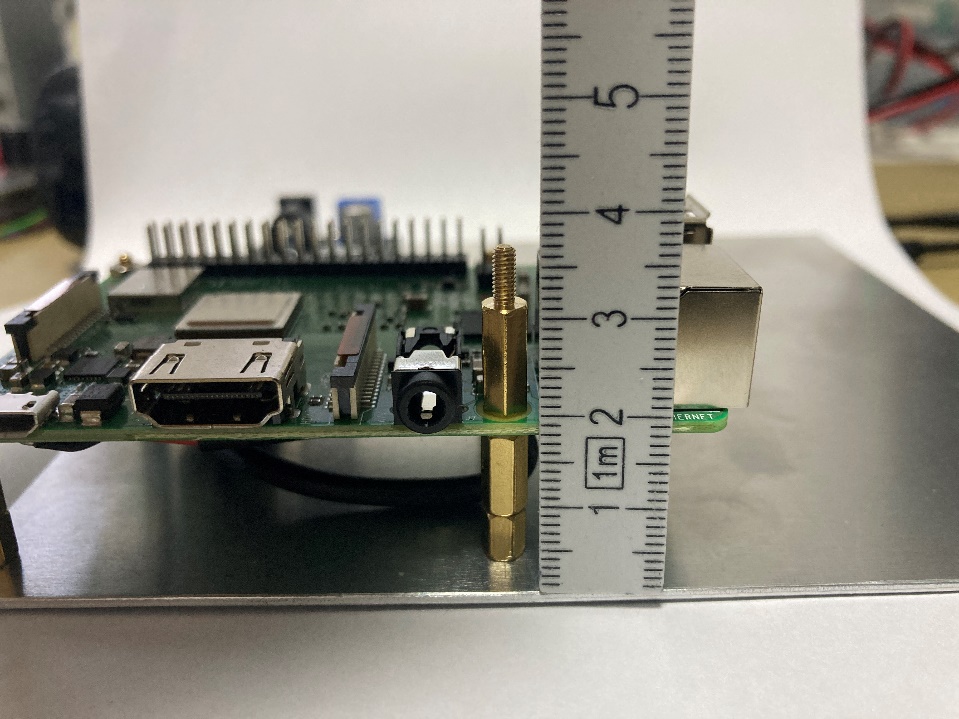
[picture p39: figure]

use 2.5x6+6 + 2.5x10+6 (4x) + 4x Nylon Flat or 2.5*15+6 (4x) + 8x Nylon Flat or similar high // 2x 2.5 nuts // 2x 2.5x12+6

4) Assemble and attach pihat to RPI with spacer (see above)

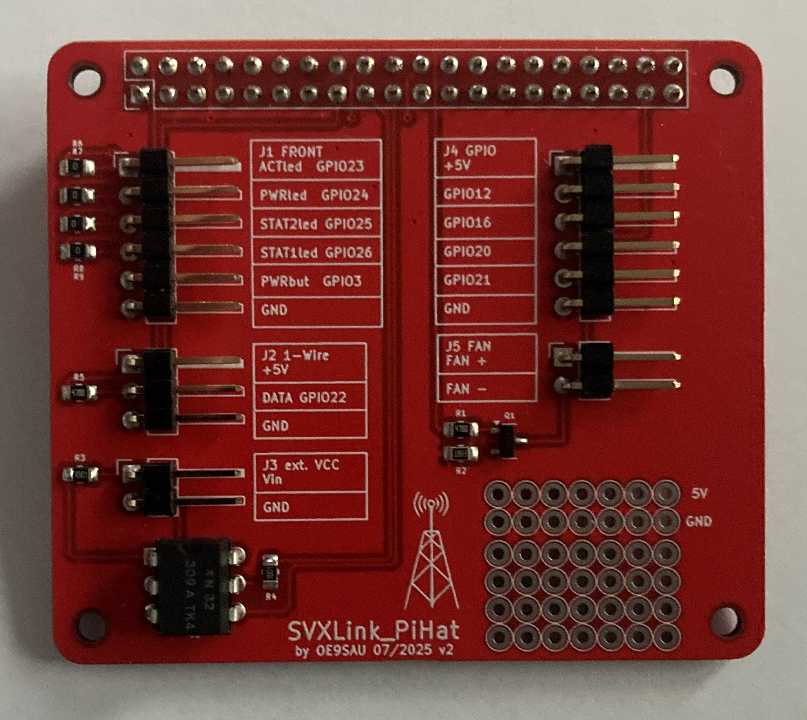
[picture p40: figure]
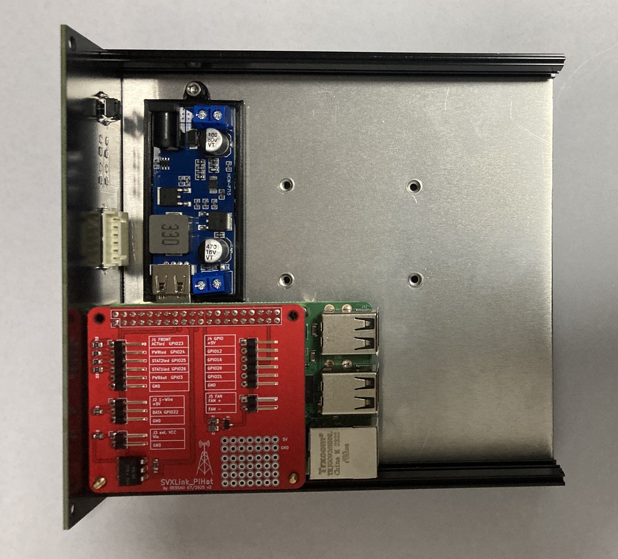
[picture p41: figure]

5) connecting front plate

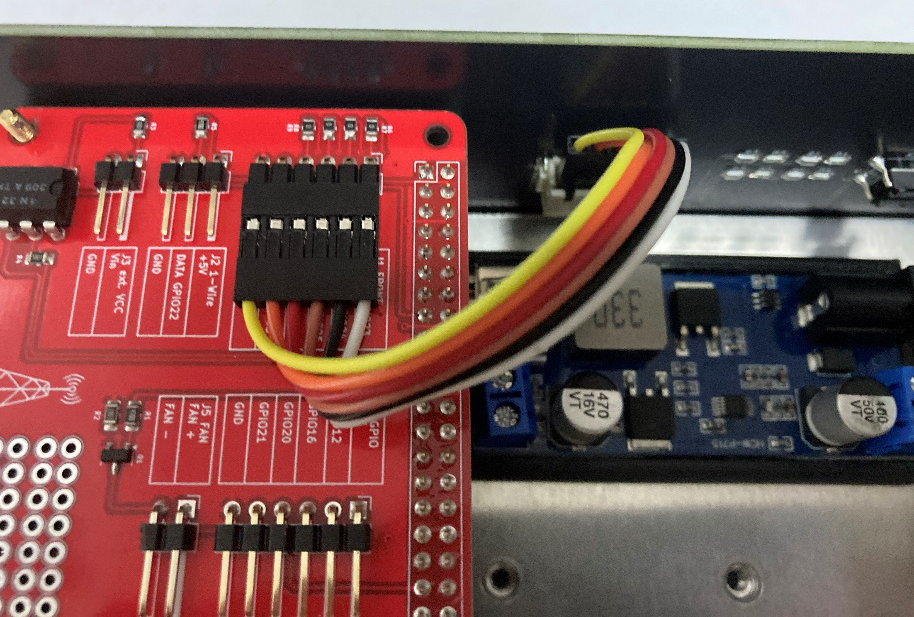
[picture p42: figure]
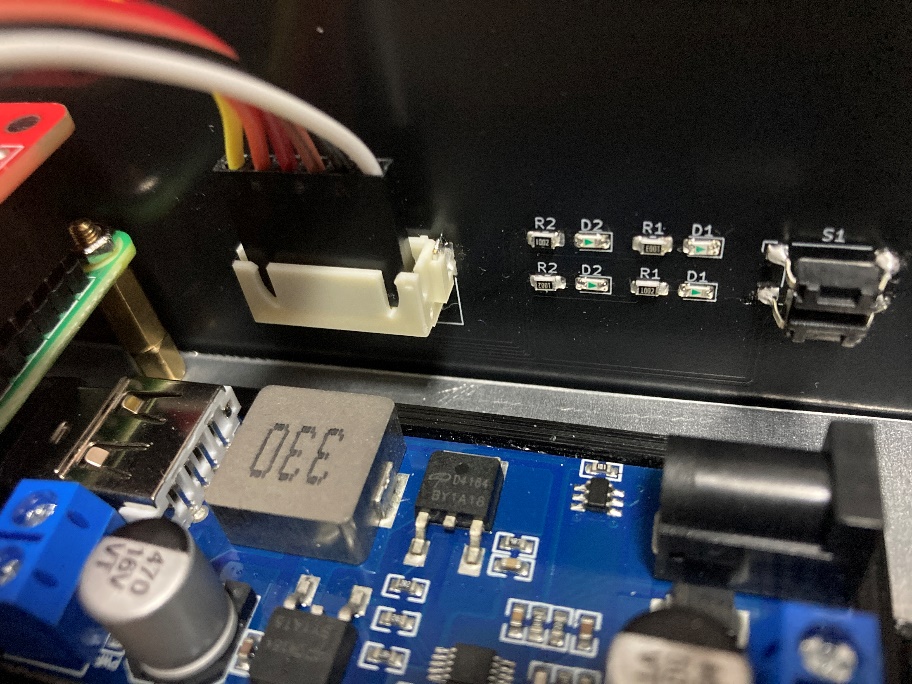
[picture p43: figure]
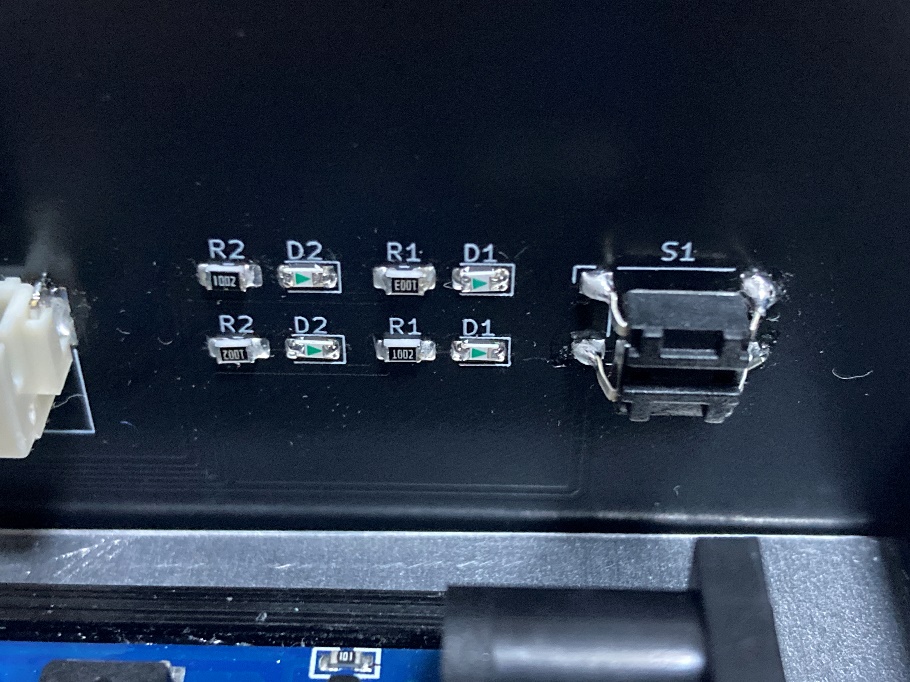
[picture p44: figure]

7) connectors for backplate

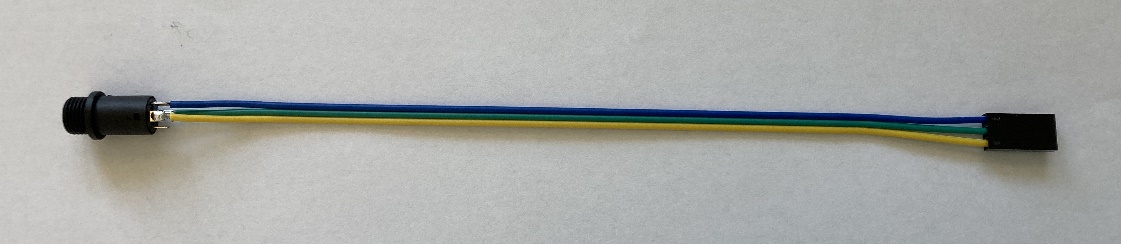
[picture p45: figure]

1-Wire jack socket

1 | GND
2 | 5V
3 | Data
4 | ------

1-Wire jack plug

5V

Data

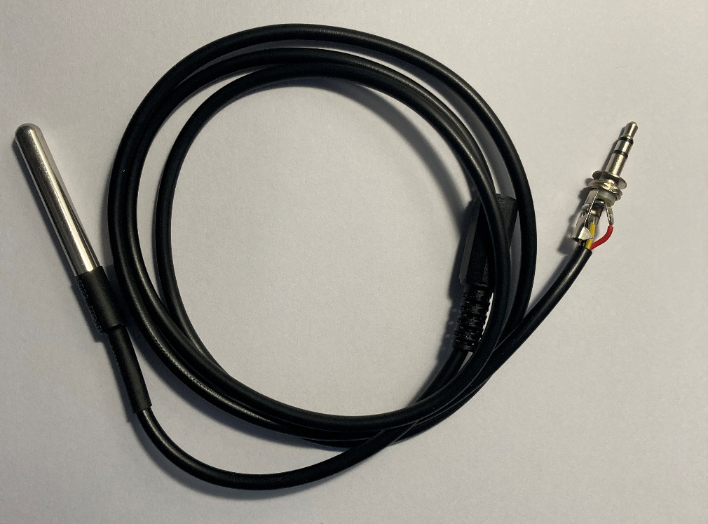
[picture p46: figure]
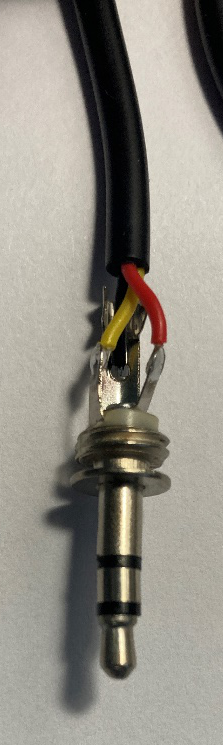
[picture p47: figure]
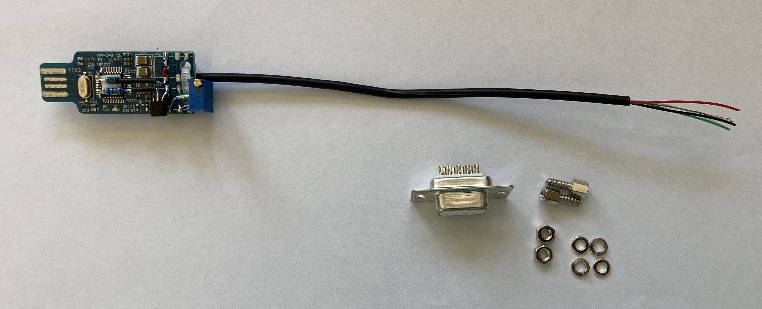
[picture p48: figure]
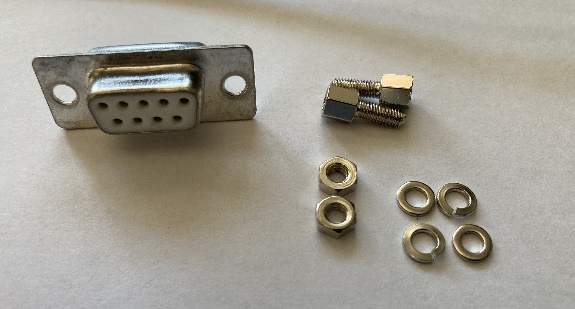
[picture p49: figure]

Sub-D | Farbe
1 | shield | GND
2 | black | PTT, Aktiv LOW
4 | red | CTCSS/SQL
5 | brown | 12V OUT (GM340 Pin 10, Ignition)
7 | white | Output = TX Audio
9 | green | Input = RX Audio

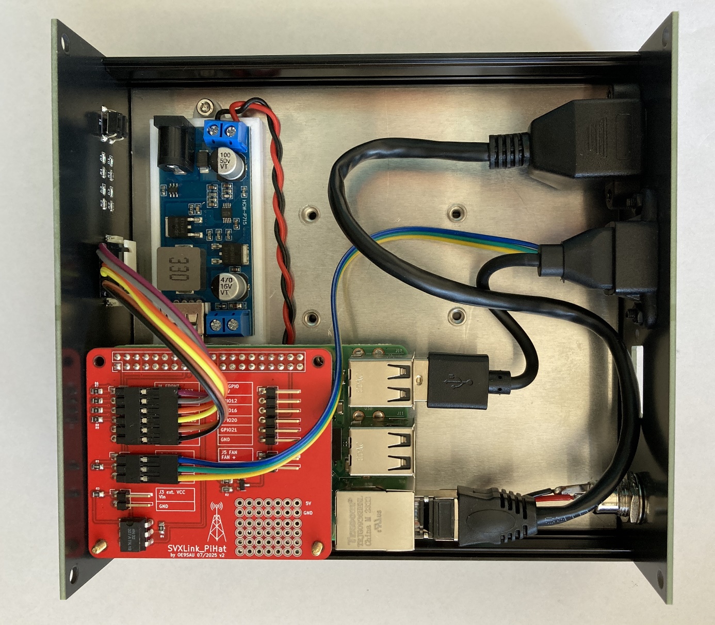
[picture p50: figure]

SAULink9 assembly

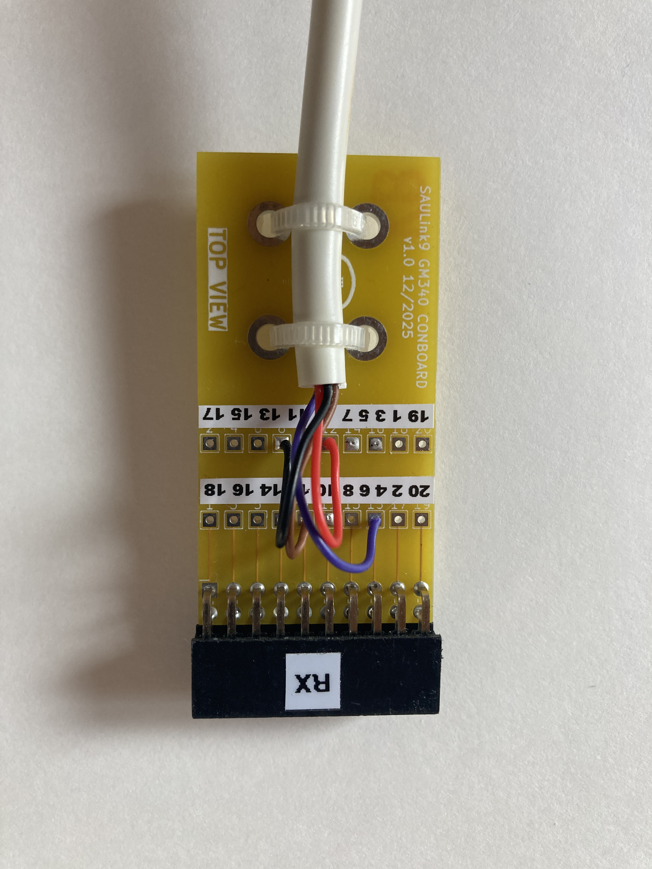
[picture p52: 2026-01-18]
Node_Case/Node_assembly/pics/CONBOARD_GM340_RX.JPG

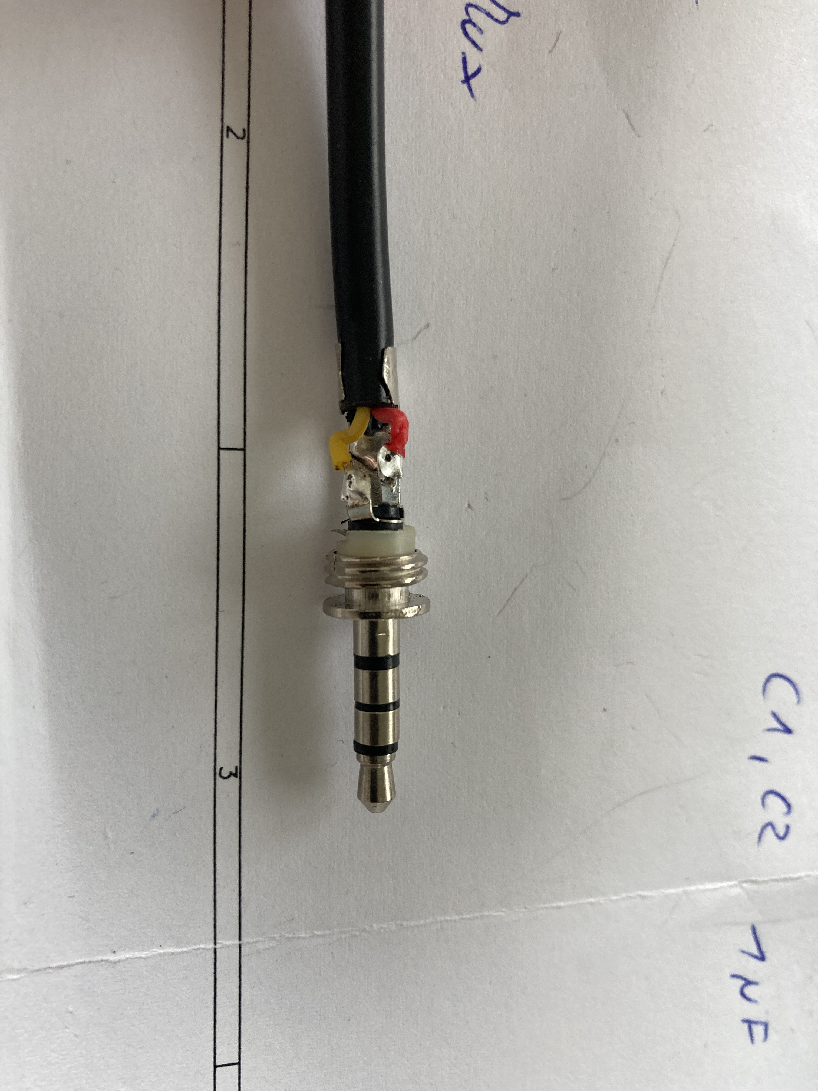
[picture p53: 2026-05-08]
Node_Case/Node_assembly/pics/IMG_2939.JPG

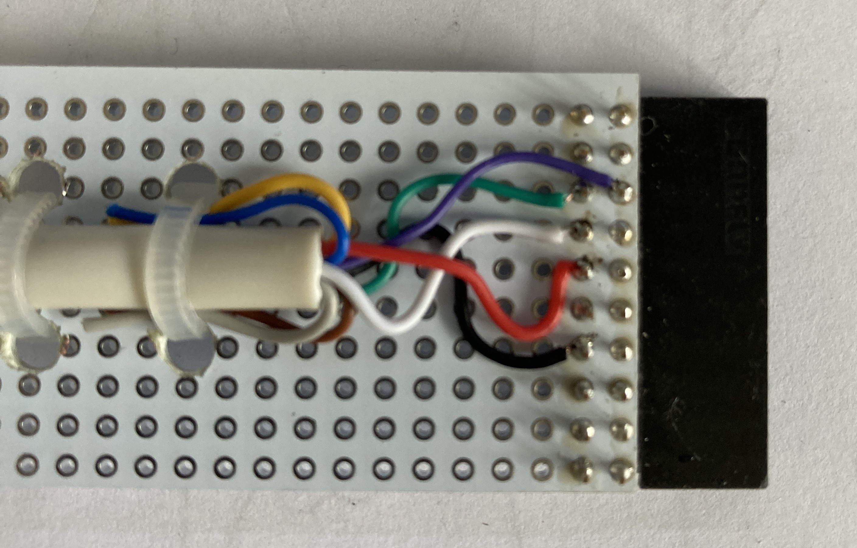
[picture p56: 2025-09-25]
Node_Case/Node_assembly/pics/IMG_1303.JPG

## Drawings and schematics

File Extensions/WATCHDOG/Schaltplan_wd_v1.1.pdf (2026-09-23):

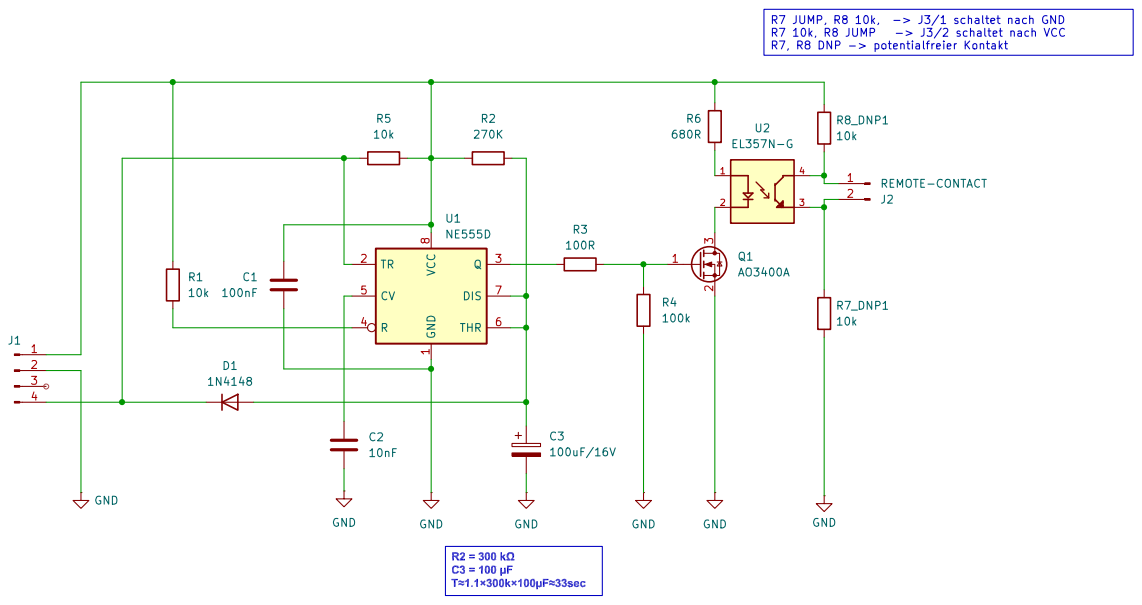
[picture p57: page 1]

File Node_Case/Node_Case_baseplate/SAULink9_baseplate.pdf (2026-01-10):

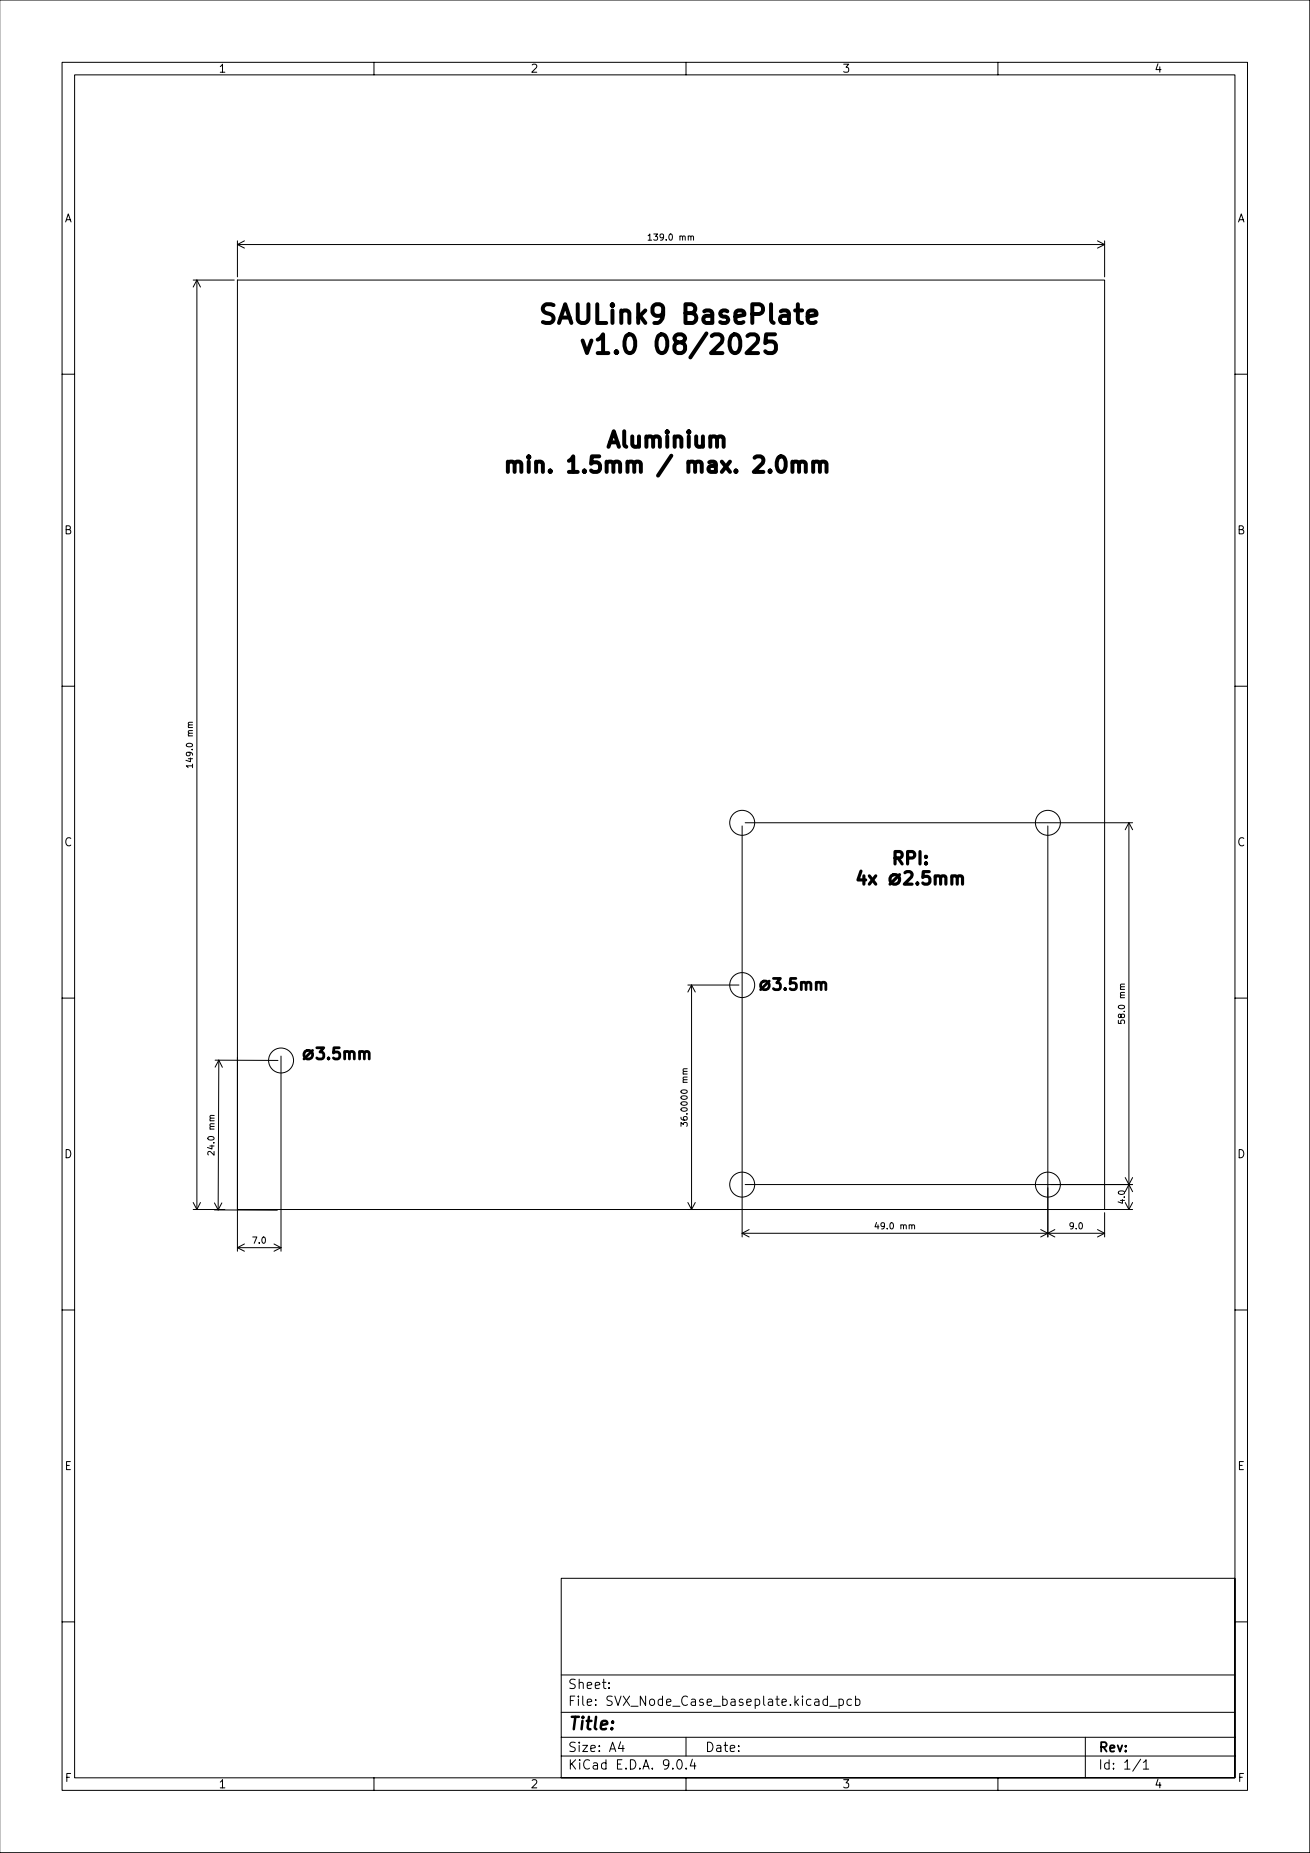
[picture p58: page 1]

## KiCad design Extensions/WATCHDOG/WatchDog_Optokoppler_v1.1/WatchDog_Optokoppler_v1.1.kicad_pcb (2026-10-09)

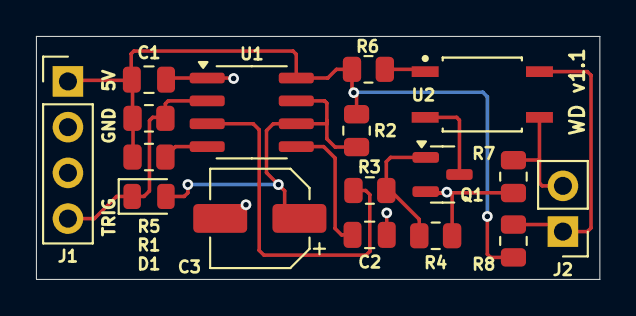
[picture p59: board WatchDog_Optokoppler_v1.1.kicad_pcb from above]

Board: 2 copper layers, 31.3 x 13.5 mm, 17 parts (0 on the bottom side), 12 nets.

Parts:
C1: 100nF; C_0805_2012Metric
C2: 10nF; C_0805_2012Metric
C3: 100uF/16V; CP_Elec_5x5.9
D1: 1N4148; D_0805_2012Metric
J1: Conn_01x04_Pin; PinHeader_1x04_P2.54mm_Vertical
J2: REMOTE-CONTACT; PinHeader_1x02_P2.54mm_Vertical
Q1: AO3400A; SOT-23
R1, R5, R7, R8: 10k; R_0805_2012Metric
R2: 270K; R_0805_2012Metric
R3: 100R; R_0805_2012Metric
R4: 100k; R_0805_2012Metric
R6: 680R; R_0805_2012Metric
U1: NE555D; SOIC-8_3.9x4.9mm_P1.27mm
U2: EL357N-G; OPTO_EL357N-G

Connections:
GND: C1.1, C2.1, C3.2, J1.2, Q1.2 (S), R4.1, R7.1, U1.1 (GND)
unnamed: C3.1, D1.2 (A), R2.2, U1.6 (THR), U1.7 (DIS)
unnamed: D1.1 (K), J1.4, R5.1, U1.2 (TR)
unnamed: C1.2, J1.1, R1.1, R2.1, R5.2, R6.2, R8.2, U1.8 (VCC)
unnamed: J2.1, R8.1, U2.4
unnamed: J2.2, R7.2, U2.3
unnamed: Q1.3 (D), U2.2
unnamed: Q1.1 (G), R3.2, R4.2
unnamed: R6.1, U2.1
unnamed: C2.2, U1.5 (CV)
unnamed: R3.1, U1.3 (Q)
unnamed: R1.2, U1.4 (R)

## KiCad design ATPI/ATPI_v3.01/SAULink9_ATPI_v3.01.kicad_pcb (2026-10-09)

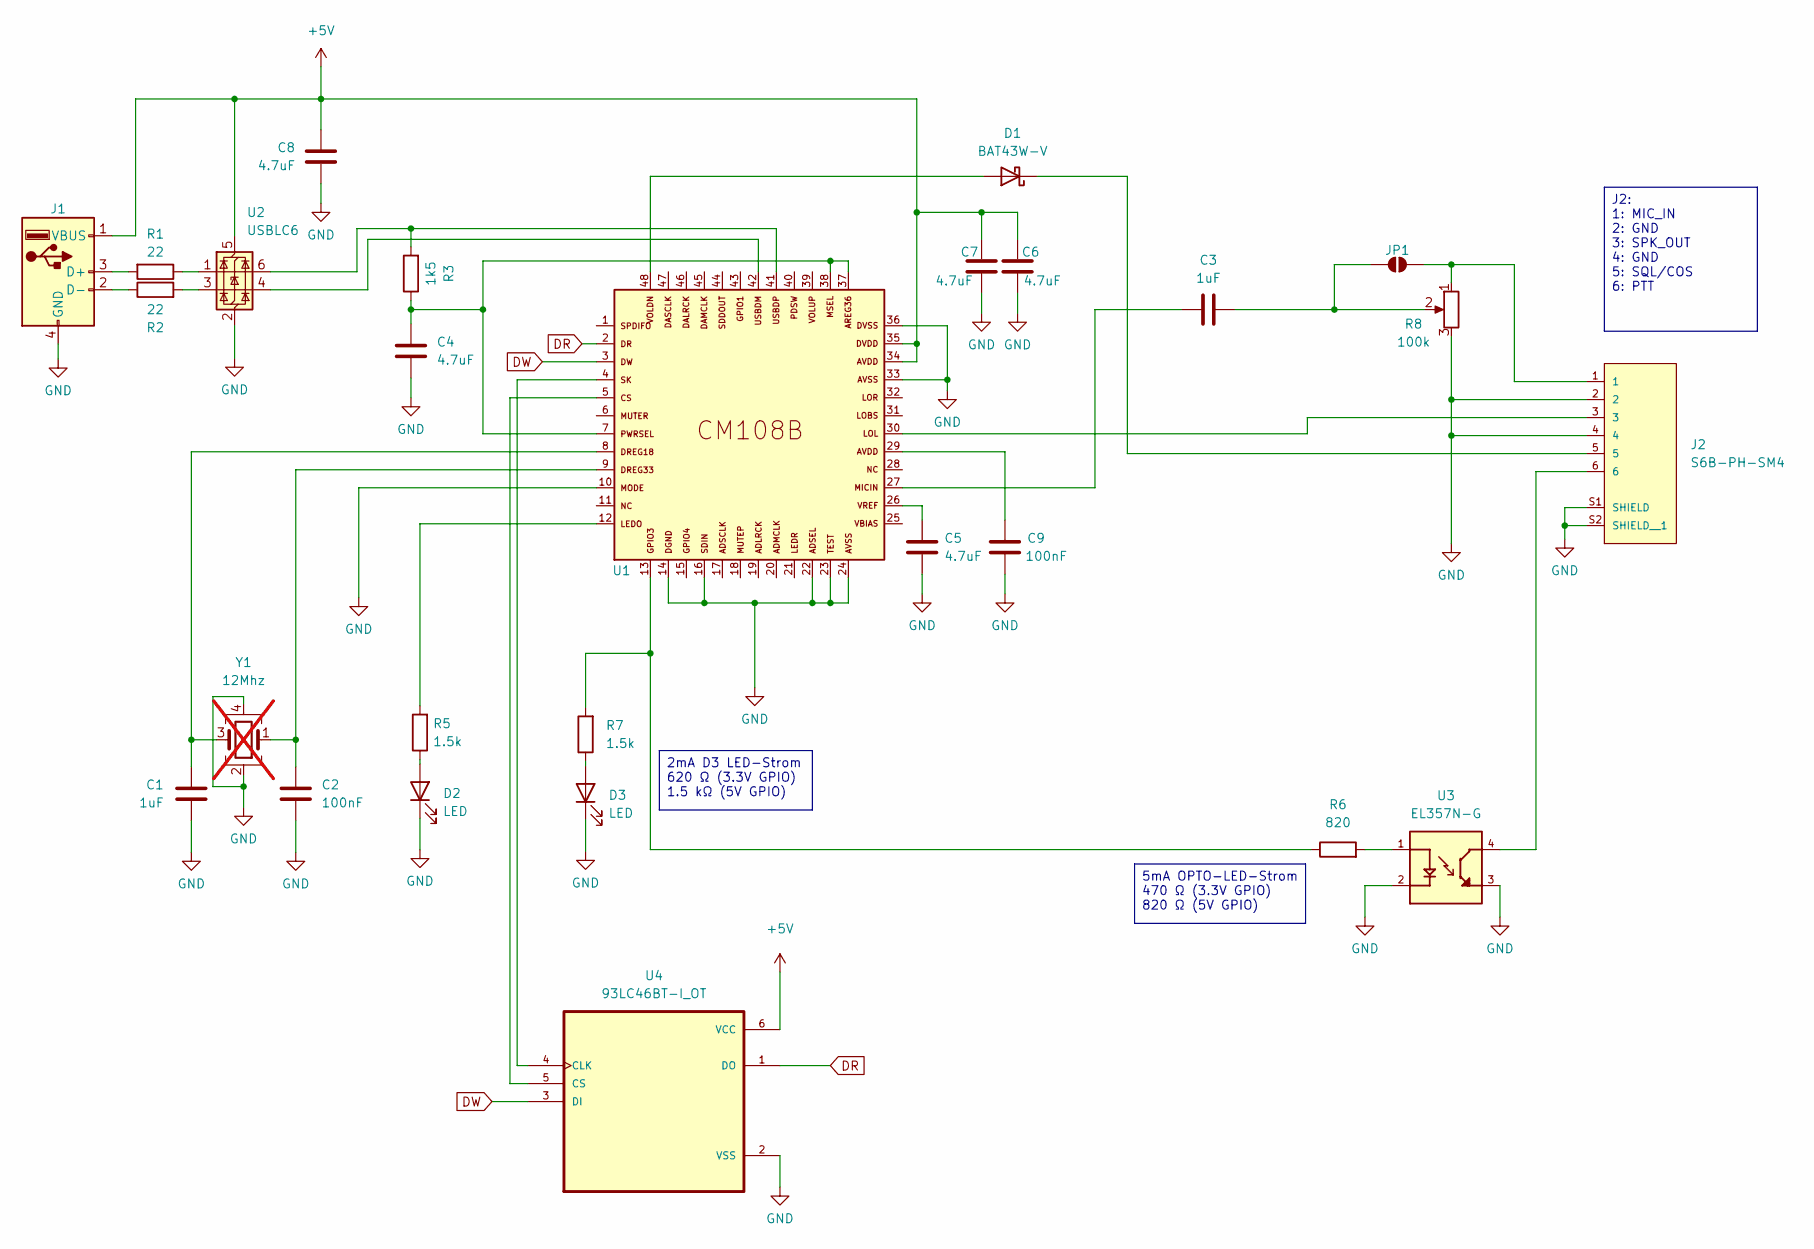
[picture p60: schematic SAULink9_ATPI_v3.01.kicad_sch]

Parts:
C1: 1uF; C_0805_2012Metric_Pad1.18x1.45mm_HandSolder
C2: 100nF; C_0805_2012Metric_Pad1.18x1.45mm_HandSolder
C3: 1uF; C_0805_2012Metric
C4, C5, C6, C7, C8: 4.7uF; C_0805_2012Metric
C9: 100nF; C_0805_2012Metric
D1: BAT43W-V; D_SOD-123
D2, D3: LED; LED_0805_2012Metric
J1: USB_A_PCB_Edge_receptacle
J2: S6B-PH-SM4; JST_S6B-PH-SM4-TB_LF__SN_
JP1: SolderJumper_2_Open
R1, R2: 22; R_0805_2012Metric
R3: 1k5; R_0805_2012Metric
R5, R7: 1.5k; R_0805_2012Metric
R6: 820; R_0805_2012Metric
R8: 100k; Potentiometer_Bourns_TC33X_Vertical
U1: CM108B; TQFP48
U2: USBLC6; SOT-23-6
U3: EL357N-G; OPTO_EL357N-G; PARTREV 6
U4: 93LC46BT-I_OT; SOT-23-6
Y1: 12Mhz; Crystal_SMD_3225-4Pin_3.2x2.5mm; not fitted

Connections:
+5V: C6.1, C7.1, C8.1, J1.1 (VBUS), U1.34, U1.35, U2.5 (VBUS), U4.6 (VCC)
DR: U1.2, U4.1 (DO)
DW: U1.3, U4.3 (DI)
GND: C1.1, C2.2, C4.2, C5.2, C6.2, C7.2, C8.2, C9.2, D2.1 (K), D3.1 (K), J1.4 (GND), J2.2, J2.4, J2.S1 (SHIELD), J2.S2 (SHIELD__1), R8.3, U1.10, U1.14, U1.16, U1.22, U1.23, U1.24, U1.33, U1.36, U2.2 (GND), U3.2, U3.3, U4.2 (VSS), Y1.2, Y1.4
unnamed: C1.2, U1.8, Y1.3
unnamed: C2.1, U1.9, Y1.1
unnamed: C3.1, U1.27
unnamed: C4.1, R3.1, U1.7, U1.37, U1.38
unnamed: C5.1, U1.26
unnamed: C9.1, U1.29
unnamed: D1.2 (A), U1.48
unnamed: D1.1 (K), J2.5
unnamed: D2.2 (A), R5.1
unnamed: D3.2 (A), R7.1
unnamed: J1.3 (D+), R1.2
unnamed: J1.2 (D-), R2.1
unnamed: J2.3, U1.30
unnamed: J2.6, U3.4
unnamed: C3.2, JP1.1 (A), R8.2
unnamed: J2.1, JP1.2 (B), R8.1
unnamed: R1.1, U2.1 (I/O1)
unnamed: R2.2, U2.3 (I/O2)
unnamed: R3.2, U1.41, U2.6 (I/O1)
unnamed: R5.2, U1.12
unnamed: R6.1, R7.2, U1.13
unnamed: R6.2, U3.1
unnamed: U1.42, U2.4 (I/O2)
unnamed: U1.4, U4.4 (CLK)
unnamed: U1.5, U4.5 (CS)

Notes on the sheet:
2mA D3 LED-Strom 620 Ω (3.3V GPIO) 1.5 kΩ (5V GPIO)
5mA OPTO-LED-Strom 470 Ω (3.3V GPIO) 820 Ω (5V GPIO)
J2: 1: MIC_IN 2: GND 3: SPK_OUT 4: GND 5: SQL/COS 6: PTT

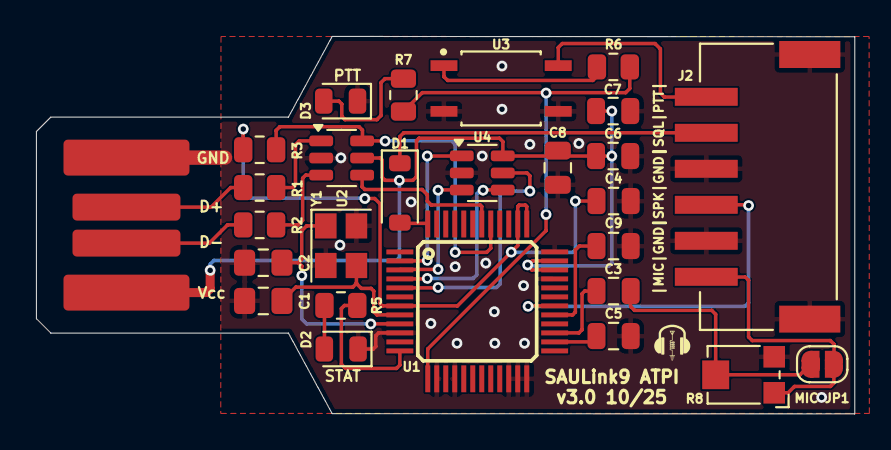
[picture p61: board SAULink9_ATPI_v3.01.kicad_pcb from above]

Board: 2 copper layers, 45.5 x 21.0 mm, 28 parts (0 on the bottom side), 29 nets.

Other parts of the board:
G10: LOGO

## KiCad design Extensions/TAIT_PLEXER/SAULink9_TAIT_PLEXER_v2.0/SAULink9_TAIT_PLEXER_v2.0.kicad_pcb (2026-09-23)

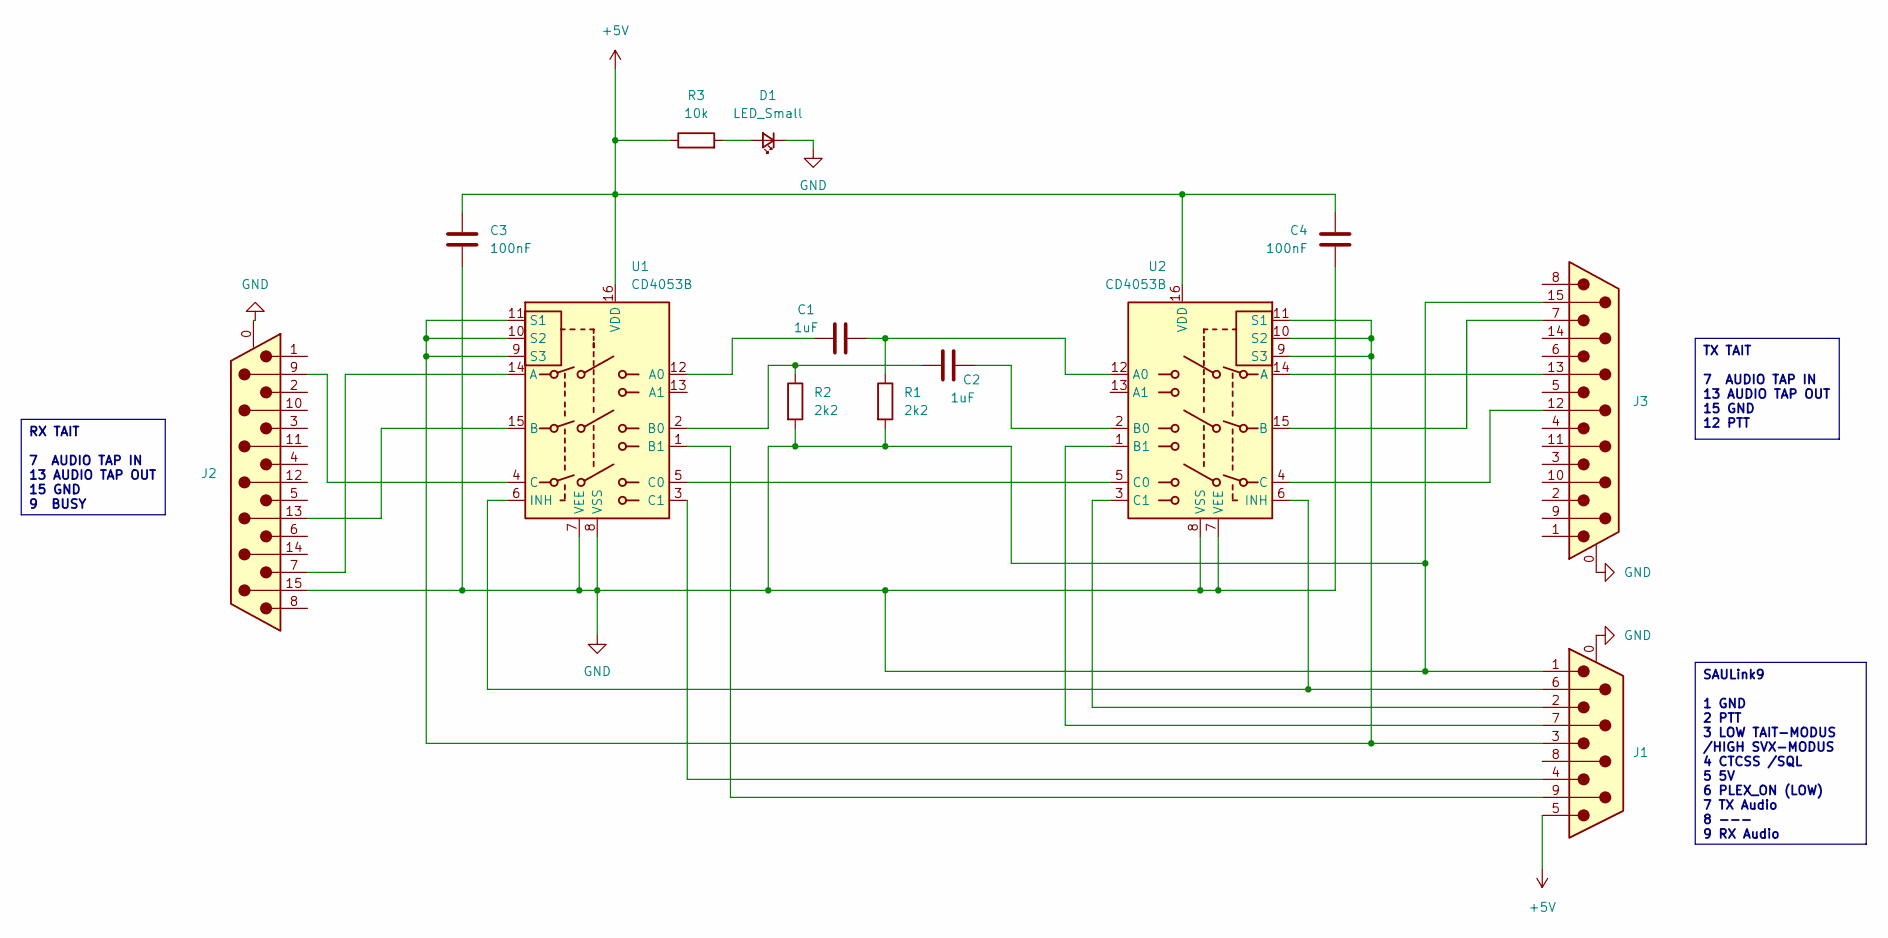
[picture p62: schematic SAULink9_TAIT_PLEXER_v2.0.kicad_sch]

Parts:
C1, C2: 1uF; C_0805_2012Metric
C3, C4: 100nF; C_0805_2012Metric
D1: LED_Small; LED_0805_2012Metric
J1: DE9_Pins; DSUB-9_Socket_Horizontal_P2.77x2.84mm_EdgePinOffset7.70mm_H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
J2, J3: DA15_Pins_MountingHoles; DSUB-15_Socket_Horizontal_P2.77x2.84mm_EdgePinOffset7.70mm_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
R1, R2: 2k2; R_0805_2012Metric
R3: 10k; R_0805_2012Metric
U1, U2: CD4053B; SOP-16_4.55x10.3mm_P1.27mm

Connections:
+5V: C3.1, C4.1, J1.5, R3.1, U1.16 (VDD), U2.16 (VDD)
GND: C3.2, C4.2, D1.1 (K), J1.0 (PAD), J1.1, J2.0 (PAD), J2.15, J3.0 (PAD), J3.15, R1.2, R2.2, U1.7 (VEE), U1.8 (VSS), U2.7 (VEE), U2.8 (VSS)
unnamed: D1.2 (A), R3.2
unnamed: J2.9, U1.4 (C)
unnamed: J2.13, U1.15 (B)
unnamed: J3.12, U2.4 (C)
unnamed: J3.13, U2.14 (A)
unnamed: C1.1, U1.12 (A0)
unnamed: J2.7, U1.14 (A)
unnamed: C2.1, R2.1, U1.2 (B0)
unnamed: J1.9, U1.1 (B1)
unnamed: U1.5 (C0), U2.5 (C0)
unnamed: J1.4, U1.3 (C1)
unnamed: J1.6, U1.6 (INH), U2.6 (INH)
unnamed: J1.3, U1.9 (S3), U1.10 (S2), U1.11 (S1), U2.9 (S3), U2.10 (S2), U2.11 (S1)
unnamed: C1.2, R1.1, U2.12 (A0)
unnamed: C2.2, U2.2 (B0)
unnamed: J1.7, U2.1 (B1)
unnamed: J3.7, U2.15 (B)
unnamed: J1.2, U2.3 (C1)

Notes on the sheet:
SAULink9 1 GND 2 PTT 3 LOW TAIT-MODUS /HIGH SVX-MODUS 4 CTCSS /SQL 5 5V 6 PLEX_ON (LOW) 7 TX Audio 8 --- 9 RX Audio
RX TAIT 7 AUDIO TAP IN 13 AUDIO TAP OUT 15 GND 9 BUSY
TX TAIT 7 AUDIO TAP IN 13 AUDIO TAP OUT 15 GND 12 PTT

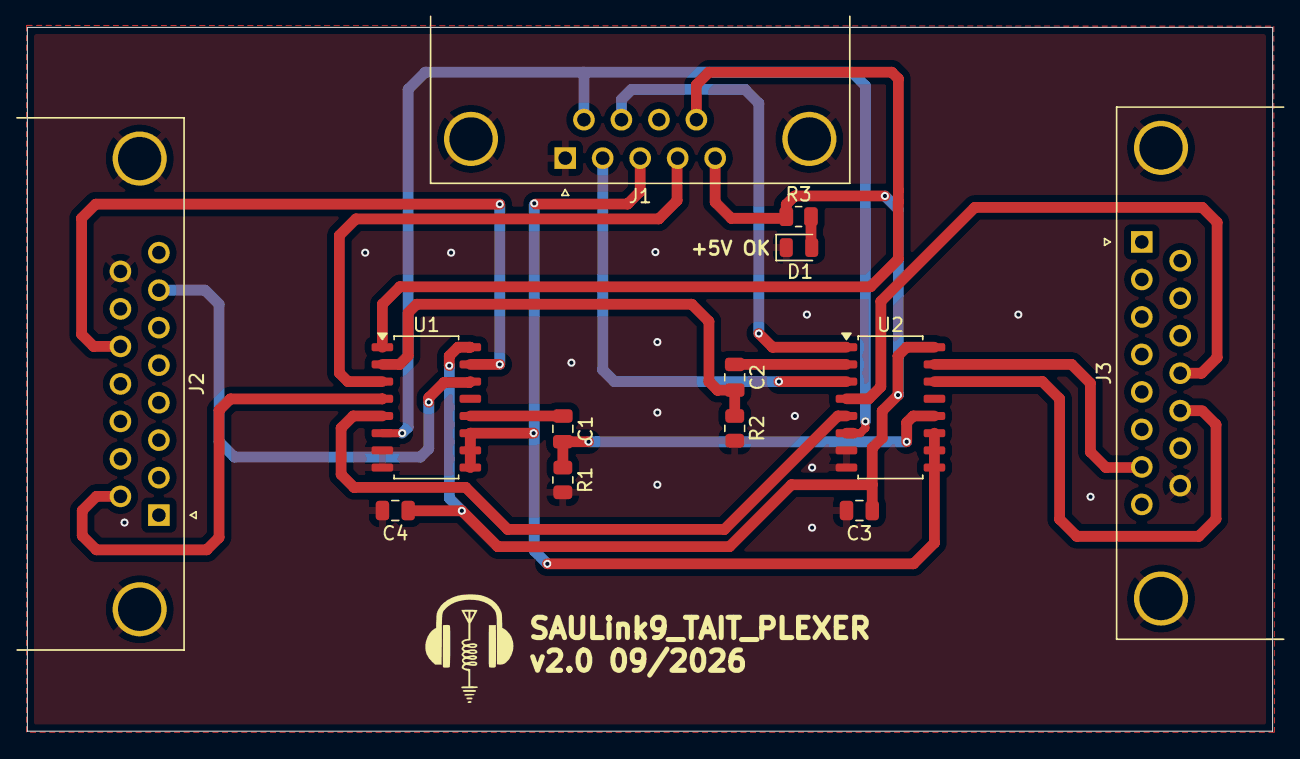
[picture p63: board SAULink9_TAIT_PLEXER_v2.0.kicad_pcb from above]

Board: 2 copper layers, 92.0 x 52.0 mm, 15 parts (1 on the bottom side), 20 nets.

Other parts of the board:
G1, G2: LOGO

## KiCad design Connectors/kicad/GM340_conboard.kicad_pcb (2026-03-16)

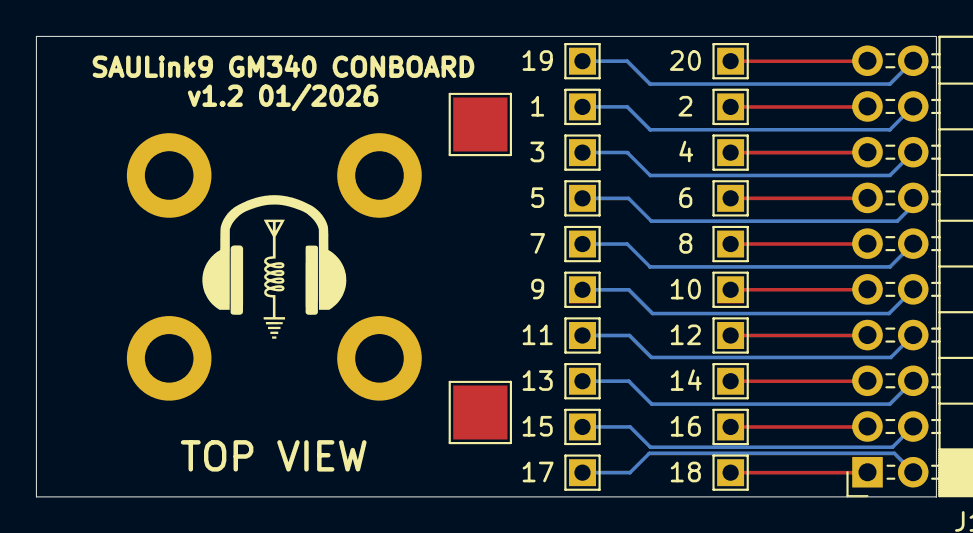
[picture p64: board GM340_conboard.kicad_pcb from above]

Board: 2 copper layers, 50.0 x 25.6 mm, 27 parts (1 on the bottom side), 20 nets.

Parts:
1, 2, 3, 4, 5, 6, 7, 8, 9, 10, 11, 12, 13, 14, 15, 16, 17, 18, 19, 20: TestPoint; TestPoint_THTPad_1.5x1.5mm_Drill0.7mm
G1, G2: LOGO
J1: Conn_02x10_Top_Bottom; PinSocket_2x10_P2.54mm_Horizontal
REF1, REF2, REF3, REF4: MountingHole_2.7mm_M2.5_DIN965_Pad

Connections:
unnamed: 18.1, J1.1
unnamed: 17.1, J1.2
unnamed: 16.1, J1.3
unnamed: 15.1, J1.4
unnamed: 14.1, J1.5
unnamed: 13.1, J1.6
unnamed: 12.1, J1.7
unnamed: 11.1, J1.8
unnamed: 10.1, J1.9
unnamed: 9.1, J1.10
unnamed: 8.1, J1.11
unnamed: 7.1, J1.12
unnamed: 6.1, J1.13
unnamed: 5.1, J1.14
unnamed: 4.1, J1.15
unnamed: 3.1, J1.16
unnamed: 2.1, J1.17
unnamed: 1.1, J1.18
unnamed: 20.1, J1.19
unnamed: 19.1, J1.20

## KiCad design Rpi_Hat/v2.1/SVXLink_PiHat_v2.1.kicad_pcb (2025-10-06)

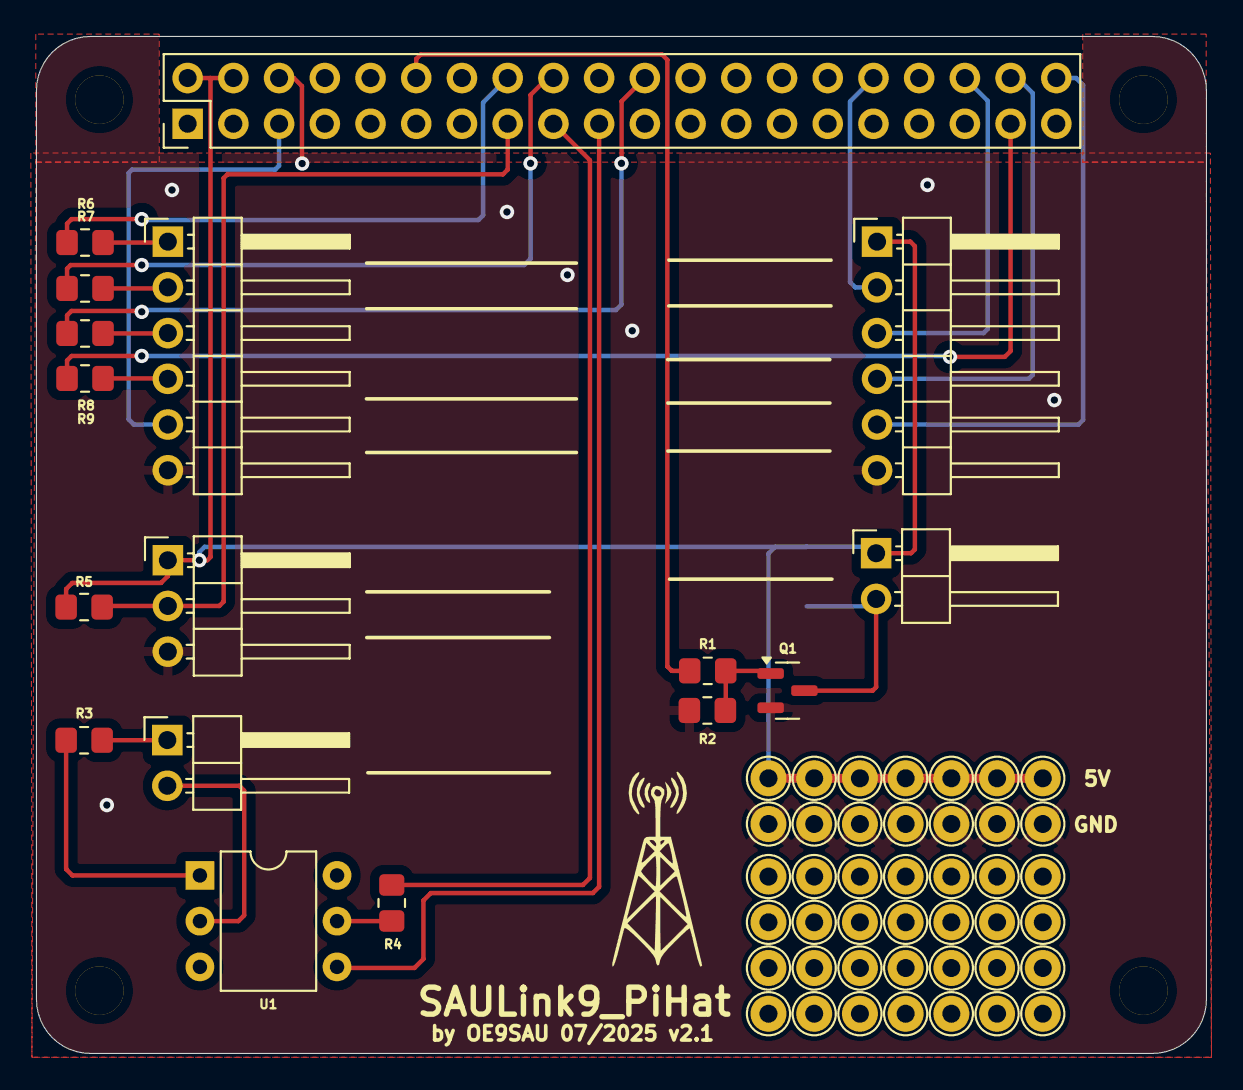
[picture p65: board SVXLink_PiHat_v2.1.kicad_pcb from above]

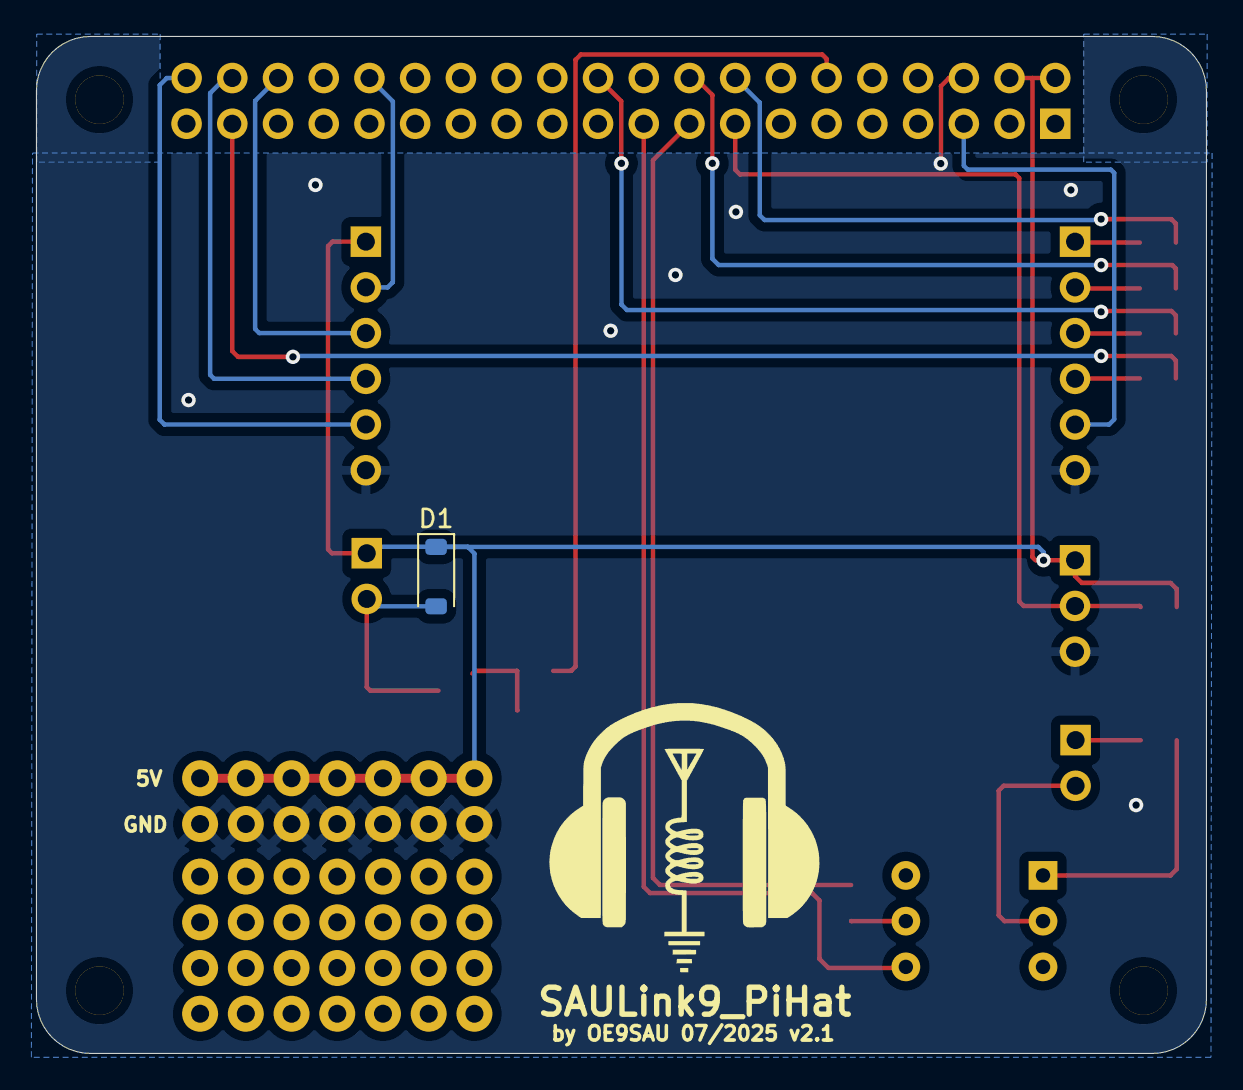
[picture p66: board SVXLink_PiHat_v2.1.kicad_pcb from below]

Board: 2 copper layers, 65.0 x 56.5 mm, 66 parts (2 on the bottom side), 25 nets.

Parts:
D1: 1N4148; D_SOD-123
G1: LOGO
G10: LOGO
J1: Raspberry_Pi_3; ESQ-120-14-T-D
J2: TRX; PinHeader_1x02_P2.54mm_Horizontal
J3: 1-Wire; PinHeader_1x03_P2.54mm_Horizontal
J4: FronPanel; PinHeader_1x06_P2.54mm_Horizontal
J4#2: RelayModule; PinHeader_1x06_P2.54mm_Horizontal
M1: Fan; PinHeader_1x02_P2.54mm_Horizontal
Q1: AO3400A; SOT-23
R1, R5: 470; R_0805_2012Metric_Pad1.20x1.40mm_HandSolder
R2: 100k; R_0805_2012Metric_Pad1.20x1.40mm_HandSolder
R3, R4: 1k; R_0805_2012Metric_Pad1.20x1.40mm_HandSolder
R6, R7, R8, R9: 0R; R_0805_2012Metric_Pad1.20x1.40mm_HandSolder
REF1, REF2, REF3, REF4: MountingHole_2.7mm_M2.5
TP1, TP2, TP3, TP4, TP5, TP6, TP7, TP8, TP9, TP10, TP11, TP12, TP13, TP14, TP15, TP16, TP17, TP18, TP19, TP20, TP21, TP22, TP23, TP24, TP25, TP26, TP27, TP28, TP29, TP30, TP31, TP31#2, TP32, TP33, TP34, TP35, TP35#2, TP36, TP37, TP321, TP333, TP341: TestPoint; TestPoint_THTPad_D2.0mm_Drill1.0mm
U1: 4N37; DIP-6_W7.62mm

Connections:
+3.3V: J1.1 (3V3), J1.17 (3V3), R4.2
+5V: D1.1 (K), J1.2 (5V), J1.4 (5V), J3.1, J4#2.1, M1.1 (+), R5.1, TP1.1, TP6.1, TP11.1, TP16.1, TP21.1, TP26.1, TP31#2.1
GND: J1.6 (GND), J3.3, J4.6, J4#2.6, Q1.2 (S), R2.2, TP2.1, TP7.1, TP12.1, TP17.1, TP22.1, TP27.1, TP321.1
GPIO3: J1.5 (SCL/GPIO3), J4.5
unnamed: D1.2 (A), M1.2 (-), Q1.3 (D)
unnamed: J1.36 (GPIO16), J4#2.3
unnamed: J1.12 (GPIO18/PWM0), R1.1
unnamed: J1.38 (GPIO20/MOSI1), J4#2.4
unnamed: J1.40 (GPIO21/SCLK1), J4#2.5
unnamed: J1.15 (GPIO22), J3.2, R5.2
unnamed: J1.16 (GPIO23), R6.2
unnamed: J1.18 (GPIO24), R7.2
unnamed: J1.22 (GPIO25), R8.2
unnamed: J1.37 (GPIO26), R9.2
unnamed: J1.19 (MOSI0/GPIO10), U1.4
unnamed: J1.32 (PWM0/GPIO12), J4#2.2
unnamed: J2.1, R3.1
unnamed: J2.2, U1.2
unnamed: J4.1, R6.1
unnamed: J4.2, R7.1
unnamed: J4.3, R8.1
unnamed: J4.4, R9.1
unnamed: Q1.1 (G), R1.2, R2.1
unnamed: R3.2, U1.1
unnamed: R4.1, U1.5

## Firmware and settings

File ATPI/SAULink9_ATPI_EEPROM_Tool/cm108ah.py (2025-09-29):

# Copyright 2021, islandcontroller_ and the fiberaudio-108 contributors
# SPDX-License-Identifier: CERN-OHL-P-2.0

# ------------------------------------------------------------------------------
# fiberaudio-108
# https://github.com/islandcontroller/fiberaudio-108
#
#   CM108AH Configuration Tool
#
# Copyright © 2021 islandcontroller_ and contributors
# Licensed under CERN Open Hardware Licence Version 2 - Permissive
#-------------------------------------------------------------------------------

import argparse
from enum import IntEnum
import hexdump
import pywinusb.hid as hid
import time
from typing import *
import warnings
import yaml

class Device:
    """CM108AH USB HID access controls
    """
    _MEMORY_SIZE_WORDS: int = 44
    _VENDOR_ID: int = 0x0D8C
    _PRODUCT_ID: int = 0x013C

    class Report:
        """Generic HID report
        """
        def __init__(self, report_num: int):
            """Instantiate generic HID report

            Args:
                report_num (int): Report number
            """
            self._report_num = report_num

        def get_data(self) -> List[int]:
            """Get raw generic HID report data

            Returns:
                List[int]: Raw HID report data
            """
            return [self._report_num]

    class OutReport(Report):
        """Generic CM108AH HID Out report
        """
        _ACCESS_EEPROM = 0x80
        _ACCESS_GPIO = 0x00

        class HidReg(IntEnum):
            """HID Out register definitions
            """
            HID_OR0 = 0
            HID_OR1 = 1
            HID_OR2 = 2
            HID_OR3 = 3

        def __init__(self, report_num: int):
            """Instantiate new HID Out report

            Args:
                report_num (int): HID report number (0)
            """
            super().__init__(report_num)
            self._regs = [0x00] * 4

        def set_reg(self, reg: HidReg, value: int):
            """Set register content

            Args:
                reg (HidReg): Register selector
                value (int): Register value (byte)

            Raises:
                ValueError: Register selector out of range
                ValueError: Register value out of range
            """
            if reg < 0 or reg > 3:
                raise ValueError('Invalid register selection')
            if value > 0xFF:
                raise ValueError('Value out of range')
            self._regs[reg] = value
        
        def get_reg(self, reg: HidReg) -> int:
            """Get register value

            Args:
                reg (HidReg): Register selector

            Raises:
                ValueError: Register selector out of range

            Returns:
                int: Register value
            """
            if reg < 0 or reg > 3:
                raise ValueError('Invalid register selection')
            return self._regs[reg]

        def get_data(self) -> List[int]:
            """Get raw HID Out report data

            Returns:
                List[int]: Raw HID Out report data
            """
            return [self._report_num] + self._regs

    class EepromOutReport(OutReport):
        """HID Out Report for EEPROM access
        """
        _EEPROM_READ = 0x80
        _EEPROM_WRITE = 0xC0
        _EEPROM_ADDR_MASK = 0x3F

        def __init__(self):
            """Instantiate new HID Out report
            """
            super().__init__(0)
            self.set_reg(self.HidReg.HID_OR0, self._ACCESS_EEPROM)

        def set_eeprom_ctrl(self, addr: int, write_access: bool):
            """Set control byte

            Args:
                addr (int): Word address
                write_access (bool): Select write access

            Raises:
                ValueError: EEPROM address out of range
            """
            if addr > self._EEPROM_ADDR_MASK: 
                raise ValueError('Address out of range')
            access = self._EEPROM_WRITE if write_access else self._EEPROM_READ
            self.set_reg(self.HidReg.HID_OR3, access | addr)

        def set_eeprom_data16(self, value: int):
            """Set data from word

            Args:
                value (int): Data word

            Raises:
                ValueError: Value out of range
            """
            if value > 0xFFFF:
                raise ValueError('Value out of range')
            self.set_reg(self.HidReg.HID_OR2, (value >> 8) & 0xFF)
            self.set_reg(self.HidReg.HID_OR1, value & 0xFF)

        def set_eeprom_data8(self, value: List[int]):
            """Set data from list of bytes

            Args:
                value (List[int]): List of bytes (exactly 2)

            Raises:
                ValueError: List length does not match requirement
            """
            if len(value) != 2:
                raise ValueError('Value must be int[2] list with exactly 2 elements')
            self.set_reg(self.HidReg.HID_OR1, value[0])
            self.set_reg(self.HidReg.HID_OR2, value[1])

        def get_eeprom_data16(self) -> int:
            """Get data as word

            Returns:
                int: Data as word
            """
            return (self.get_reg(self.HidReg.HID_OR2) << 8) + self.get_reg(self.HidReg.HID_OR1)

        def get_eeprom_data8(self) -> List[int]:
            """Get data as list of bytes

            Returns:
                List[int]: Data as list of bytes
            """
            return [self.get_reg(self.HidReg.HID_OR1), self.get_reg(self.HidReg.HID_OR2)]
            
    class EepromReadOutReport(EepromOutReport):
        """HID Out report for data read access
        """
        def __init__(self, addr: int):
            """Instantiate new HID Out report

            Args:
                addr (int): Word address
            """
            super().__init__()
            self.set_eeprom_ctrl(addr, False)

    class EepromWrite16OutReport(EepromOutReport):
        """HID Out report for data word write access
        """
        def __init__(self, addr: int, value: int):
            """Instantiate new HID Out report

            Args:
                addr (int): Word address
                value (int): Data word
            """
            super().__init__()
            self.set_eeprom_ctrl(addr, True)
            self.set_eeprom_data16(value)

    class EepromWrite8OutReport(EepromOutReport):
        """HID Out report for 2 data bytes write access
        """
        def __init__(self, addr: int, value: List[int]):
            """Instantiate new HID Out report

            Args:
                addr (int): Word address
                value (List[int]): Data bytes (exactly 2)
            """
            super().__init__()
            self.set_eeprom_ctrl(addr, True)
            self.set_eeprom_data8(value)

    class GpioOutReport(OutReport):
        """HID Out report for GPIO and SPDIF access
        """
        def __init__(self):
            """Instantiate new GPIO access HID Out report
            """
            super().__init__(0)
            self.set_reg(self.HidReg.HID_OR0, self._ACCESS_GPIO)

        def set_spdif_status(self, valid: bool, data: int, category: int):
            """Set SPDIF status channel values

            Args:
                valid (bool): SPDIF status channel valid flag
                data (int): SPDIF status channel data nibble
                categoriy (int): SPDIF status channel category byte

            Raises:
                ValueError: Value for SPDIF status nibble out of range
                ValueError: Value for SPDIF category byte out of range
            """
            if data > 0x0F:
                raise ValueError('SPDIF status channel nibble out of range')
            if category > 0xFF:
                raise ValueError('SPDIF category byte out of range')
            self.set_reg(self.HidReg.HID_OR0, self._ACCESS_GPIO | data | (valid << 4))
            self.set_reg(self.HidReg.HID_OR3, category)

        def get_spdif_status_valid(self) -> bool:
            """Get SPDIF status channel valid flag from buffer

            Returns:
                bool: Status channel valid flag
            """
            return bool(self.get_reg(self.HidReg.HID_OR0) & 0x10)

        def get_spdif_status_data(self) -> int:
            """Get SPDIF status channel nibble from buffer

            Returns:
                int: SPDIF status channel nibble
            """
            return self.get_reg(self.HidReg.HID_OR0) & 0xF

        def get_spdif_status_cat(self) -> int:
            """Get SPDIF status channel category byte from buffer

            Returns:
                int: SPDIF status channel category byte
            """
            return self.get_reg(self.HidReg.HID_OR3)

        def set_gpio_data_reg(self, value: int):
            """Set GPIO data register

            Args:
                value (int): GPIO data register value (bit-masked output HIGH/LOW states)

            Raises:
                ValueError: GPIO data register value out of range
            """
            if value > 0x0F:
                raise ValueError('GPIO data value out of range')
            self.set_reg(self.HidReg.HID_OR1, value)

        def get_gpio_data_reg(self) -> int:
            """Get GPIO data register from buffer

            Returns:
                int: GPIO data register value
            """
            return self.get_reg(self.HidReg.HID_OR1)

        def set_gpio_dir_reg(self, value: int):
            """Set GPIO direction register value

            Args:
                value (int): GPIO direction register value (bit-masked out/in states)

            Raises:
                ValueError: GPIO direction register value out of range
            """
            if value > 0x0F:
                raise ValueError('GPIO direction value out of range')
            self.set_reg(self.HidReg.HID_OR2, value)

        def get_gpio_dir_reg(self) -> int:
            """Get GPIO direction register value from buffer

            Returns:
                int: GPIO direction register value
            """
            return self.get_reg(self.HidReg.HID_OR2)

    class InReport(Report):
        """Generic CM108AH HID In Report
        """
        class HidReg(IntEnum):
            """HID In register definitions
            """
            HID_IR0 = 0
            HID_IR1 = 1
            HID_IR2 = 2
            HID_IR3 = 3

        def __init__(self, data: List[int]):
            """Create new generic CM108 HID In report from raw data

            Args:
                data (List[int]): Raw HID In report data

            Raises:
                ValueError: Data does not match length requirements
            """
            if len(data) != 5:
                raise ValueError('Register list must contain exactly 5 items')
            
            report_num = data[0]
            regs = data[1:5]

            super().__init__(report_num)
            self._regs = regs

        def get_reg(self, reg: HidReg) -> int:
            """Get register value

            Args:
                reg (HidReg): Register selection

            Raises:
                ValueError: Register selector out of range

            Returns:
                int: Register value
            """
            if reg < 0 or reg > 3:
                raise ValueError('Invalid register selection')
            return self._regs[reg]

        def get_data(self) -> List[int]:
            """Get raw HID In report data

            Returns:
                List[int]: Raw HID In report data
            """
            return [self._report_num] + self._regs

    class EepromInReport(InReport):
        """HID In Report containing EEPROM data
        """
        def __init__(self, data: List[int]):
            """Instantiate EEPROM In Report from raw data

            Args:
                data (List[int]): Raw HID In report data
            """
            super().__init__(data)

        def get_eeprom_data16(self) -> int:
            """Get EEPROM data word

            Returns:
                int: EEPROM data word
            """
            return (self.get_reg(self.HidReg.HID_IR2) << 8) + self.get_reg(self.HidReg.HID_IR1)

        def get_eeprom_data8(self) -> List[int]:
            """Get EEPROM data as bytes list

            Returns:
                List[int]: EEPROM data fields as byte list
            """
            return [self.get_reg(self.HidReg.HID_IR1), self.get_reg(self.HidReg.HID_IR2)]

    class GpioInReport(InReport):
        """HID In report containing GPIO data
        """
        def __init__(self, data: List[int]):
            """Instantiate GPIO In report from raw data

            Args:
                data (List[int]): Raw HID In report data
            """
            super().__init__(data)

        def get_gpio_data_reg(self) -> int:
            """Get GPIO data register from buffer

            Returns:
                int: GPIO data register value
            """
            return self.get_reg(self.HidReg.HID_IR1)

        def get_gpio_buttons(self) -> int:
            """Get button states from buffer

            Returns:
                int: Button states
            """
            return self.get_reg(self.HidReg.HID_IR0) & 0xF

    class Button(IntEnum):
        """CM108 Button definitions
        """
        VOLUME_UP = 0x01
        VOLUME_DOWN = 0x02
        PLAY_MUTE = 0x04
        RECORD_MUTE = 0x08

    @classmethod
    def GetAvailableDevices(cls, vid: int = _VENDOR_ID, pid: int = None) -> List[hid.HidDevice]:
        """List all available devices matching VID/PID

        Args:
            vid: Vendor ID. Defaults to CMedia Vendor ID.
            pid: Product ID. Defaults to None (no filter).

        Returns:
            List[hid.HidDevice]: List of available HIDDevices matching VID/PID
        """
        if not pid: return hid.HidDeviceFilter(vendor_id=vid).get_devices()
        else:       return hid.HidDeviceFilter(vendor_id=vid, product_id=pid).get_devices()

    def __init__(self, device: hid.HidDevice):
        """Instantiate new CM108 Device handler from HIDDevice

        Args:
            device (hid.HidDevice): Underlying HIDDevice
        """
        self._hid_device: hid.HidDevice = device
        self._gpio_buttons: int = 0
        self._gpio_data: int = 0
        self._gpio_dir: int = 0

    def open(self):
        """Open underlying HID and assign HID in/out reports
        """
        self._hid_device.open()
        self._in_report = self._hid_device.find_input_reports()[0]
        self._out_report = self._hid_device.find_output_reports()[0]
        
    def read16(self, addr: int, num_words: int = 1) -> List[int]:
        """Read from EEPROM into list of words

        Args:
            addr (int): Start word address
            num_words (int, optional): Number of words to read. Defaults to 1.

        Raises:
            IOError: Failed to send USB HID out report

        Returns:
            List[int]: EEPROM data as list of words
        """
        data = []
        for offset in range(0, num_words):
            # Generate and send USB HID out report
            read_out_report = self.EepromReadOutReport(addr + offset)
            self._out_report.set_raw_data(read_out_report.get_data())
            
            if not self._out_report.send():
                raise IOError('Failed to send out report')

            # Readback data
            in_data = self._in_report.get()
            read_in_report = self.EepromInReport(in_data)

            # Append to buffer
            data = data + [read_in_report.get_eeprom_data16()]
            
        return data

    def read8(self, addr: int, num_words: int = 1) -> List[int]:
        """Read from EERPOM into list of bytes

        Args:
            addr (int): Start word address
            num_words (int, optional): Number of **words** to read. Defaults to 1.

        Raises:
            IOError: Failed to send USB HID Out report

        Returns:
            List[int]: EEPROM data as list of bytes
        """
        data = []
        for offset in range(0, num_words):
            # Generate and send USB HID out report
            read_out_report = self.EepromReadOutReport(addr + offset)
            self._out_report.set_raw_data(read_out_report.get_data())
            
            if not self._out_report.send():
                raise IOError('Failed to send out report')

            # Readback data
            in_data = self._in_report.get()
            read_in_report = self.EepromInReport(in_data)

            # Append to buffer
            data = data + read_in_report.get_eeprom_data8()

        return data

    def write16(self, addr: int, data: List[int]):
        """Write array of words to EEPROM

        Args:
            addr (int): Start word address
            data (List[int]): List of words
            max_retry (int, optional): Number of write retries per address. Defaults to 0.

        Raises:
            IOError: Failed to send USB OUT report
            IOError: Repeated writes (retries) failed
        """
        for offset in range(0, len(data)):
            # Generate HID out report
            write_out_report = self.EepromWrite16OutReport(addr + offset, data[offset])
            self._out_report.set_raw_data(write_out_report.get_data())

            # Send HID Out report (optional retry)
            if not self._out_report.send():
                raise IOError('Failed to send out report')

    def write8(self, addr: int, data: List[int]):
        """Write array of bytes to EEPROM

        Args:
            addr (int): Start word address
            data (List[int]): List of bytes (multiple of 2!)
            max_retry (int, optional): Number of write retries for each address. Defaults to 0.

        Raises:
            ValueError: Length must be multiple of 2
            IOError: Failed to send USB HID out report
            IOError: Repeated writes (retries) failed
        """
        if len(data) & 0x1:
            raise ValueError('Data length must be multiple of 2')

        num_words = len(data) >> 1
        for offset in range(0, num_words):
            byte_offset = offset << 1
            
            # Generate HID Out report
            write_out_report = self.EepromWrite8OutReport(addr + offset, data[byte_offset:byte_offset+2])
            self._out_report.set_raw_data(write_out_report.get_data())

            # Send HID Out report (optional retry)
            if not self._out_report.send():
                raise IOError('Failed to send out report')

    def config_gpio(self, modes: int):
        """Configure GPIO in/out modes

        Args:
            modes (int): Output configuration

        Raises:
            ValueError: Configuration value out of range
        """
        if modes > 0x0F:
            raise ValueError('Modes value out of range')
        self._gpio_dir = modes
        self._update_gpio(self._gpio_data)

    def _update_gpio(self, data: int) -> int:
        """Send new GPIO states to the device and update inputs

        Args:
            data (int): New output states

        Raises:
            IOError: Failed to send HID report

        Returns:
            int: Updated input state buffer
        """
        # Generate HID Out report
        write_out_report = self.GpioOutReport()
        write_out_report.set_gpio_dir_reg(self._gpio_dir)
        write_out_report.set_gpio_dir_reg(data)
        self._out_report.set_raw_data(write_out_report.get_data())

        # Send report
        if not self._out_report.send():
            raise IOError('Failed to send out report')

        # Readback response
        in_data = self._in_report.get()
        write_in_report = self.GpioInReport(in_data)

        # Update internal buffers
        self._gpio_data = write_in_report.get_gpio_data_reg()
        self._gpio_buttons = write_in_report.get_gpio_buttons()
        return self._gpio_data

    def write_gpio_pin(self, pin: int, value: bool):
        """Write GPIO pin value

        Args:
            pin (int): GPIO pin number 1..4
            value (bool): Output state

        Raises:
            ValueError: GPIO pin selector out of range
        """
        if pin < 1 or pin > 4:
            raise ValueError('GPIO pin selection out of range')
        mask = 1 << (pin - 1)
        out_states = (self._gpio_data & ~mask) | (mask if value else 0)
        self._update_gpio(out_states)
    
    def write_gpio_reg(self, value: int):
        """Set GPIO data register value

        Args:
            value (int): Data register value

        Raises:
            ValueError: Register value out of range
        """
        if value > 0x0F:
            raise ValueError('GPIO data register value out of range')
        self._update_gpio(value)

    def read_gpio_pin(self, pin: int) -> bool:
        """Update cache and read pin signal state

        Args:
            pin (int): GPIO number (1-4)

        Raises:
            ValueError: GPIO number out of range

        Returns:
            bool: Pin signal state
        """
        if pin < 1 or pin > 4:
            raise ValueError('GPIO pin selection out of range')
        mask = 1 << (pin - 1)
        return bool(self._update_gpio(self._gpio_data) & mask)
        
    def read_gpio_reg(self) -> int:
        """Update chache and read GPIO pin states register

        Returns:
            int: Pin states register (GPIO1..4)
        """
        return self._update_gpio(self._gpio_data)

    def read_button(self, button: Button) -> bool:
        """Read dedicated button state

        Args:
            button (Button): Button selector or bitmask

        Raises:
            ValueError: Invalid button selector
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

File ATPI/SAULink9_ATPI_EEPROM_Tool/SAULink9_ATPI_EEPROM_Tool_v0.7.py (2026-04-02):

import os
import subprocess
import tkinter as tk
from tkinter import filedialog, messagebox, ttk
import venv
import threading

# -------------------------------------------------------
# Konfiguration
# -------------------------------------------------------
BASE_DIR = os.path.dirname(os.path.abspath(__file__))
VENV_DIR = os.path.join(BASE_DIR, ".venv")

if os.name == "nt":
    PYTHON_EXE = os.path.join(VENV_DIR, "Scripts", "pythonw.exe")
    PIP_EXE = os.path.join(VENV_DIR, "Scripts", "pip.exe")
else:
    PYTHON_EXE = os.path.join(VENV_DIR, "bin", "python")
    PIP_EXE = os.path.join(VENV_DIR, "bin", "pip")

REQUIREMENTS = os.path.join(BASE_DIR, "requirements.txt")
SCRIPT_NAME = os.path.join(BASE_DIR, "cm108ah.py")

# -------------------------------------------------------
# Fensterbasis
# -------------------------------------------------------
root = tk.Tk()
root.title("v0.7 – Dark Gradient Edition")
root.geometry("780x750")
root.resizable(False, False)
root.configure(bg="#14141a")

# -------------------------------------------------------
# Variablen
# -------------------------------------------------------
config_path_var = tk.StringVar()
status_var = tk.StringVar(value="Starte...")
progress_value = tk.IntVar(value=0)
enable_usb_ids_var = tk.IntVar(value=0)
enable_hid_bit_var = tk.IntVar(value=0)

# -------------------------------------------------------
# Farbverlauf-Header
# -------------------------------------------------------
header = tk.Canvas(root, height=80, highlightthickness=0)
header.pack(fill="x")
for i in range(780):
    r = int(0x00 + (0x4C - 0x00) * i / 780)
    g = int(0xBC + (0xAF - 0xBC) * i / 780)
    b = int(0xD4 + (0x50 - 0xD4) * i / 780)
    color = f"#{r:02x}{g:02x}{b:02x}"
    header.create_line(i, 0, i, 80, fill=color)

header.create_text(390, 40, text="⚙️ SAULink9 ATPI EEPROM Tool", fill="white",
                   font=("Segoe UI", 16, "bold"))

# -------------------------------------------------------
# Styles
# -------------------------------------------------------
style = ttk.Style()
style.theme_use("clam")
style.configure("Card.TFrame", background="#1e1e27", relief="flat")
style.configure("TLabel", background="#1e1e27", foreground="#e0e0e0", font=("Segoe UI", 10))
style.configure("TProgressbar", thickness=20, troughcolor="#2b2b38", background="#4CAF50")

# Glow-Button-Stile
style.configure("Accent.TButton",
                background="#4CAF50", foreground="white", font=("Segoe UI", 10, "bold"),
                padding=8, relief="flat")
style.map("Accent.TButton",
          background=[("active", "#6FE173"), ("pressed", "#3D944A")])

style.configure("Alt.TButton",
                background="#00BCD4", foreground="white", font=("Segoe UI", 10, "bold"),
                padding=8, relief="flat")
style.map("Alt.TButton",
          background=[("active", "#26C6DA"), ("pressed", "#0BA0B5")])

# -------------------------------------------------------
# Schattenrahmen-Helfer
# -------------------------------------------------------
def create_card(parent, **kwargs):
    shadow = tk.Frame(parent, bg="#0b0b10")
    shadow.pack(padx=8, pady=8)
    frame = ttk.Frame(shadow, style="Card.TFrame", **kwargs)
    frame.pack(padx=3, pady=3)
    return frame

# -------------------------------------------------------
# Layout
# -------------------------------------------------------
frame_top = create_card(root)
frame_middle = create_card(root)
frame_log = create_card(root)
frame_bottom = create_card(root)

# -------------------------------------------------------
# Top Frame – Datei-Auswahl
# -------------------------------------------------------
ttk.Label(frame_top, text="Konfigurationsdatei:").grid(row=0, column=0, sticky="w", padx=5, pady=8)
entry = ttk.Entry(frame_top, textvariable=config_path_var, width=60)
entry.grid(row=0, column=1, padx=5)
ttk.Button(frame_top, text="📁 Durchsuchen", style="Alt.TButton",
           command=lambda: config_path_var.set(
               filedialog.askopenfilename(filetypes=[("YAML-Dateien", "*.yaml")])
           )).grid(row=0, column=2, padx=5)

# -------------------------------------------------------
# Middle Frame – Aktionen + Flags (statisch)
# -------------------------------------------------------
ttk.Button(frame_middle, text="🔍 Geräte auflisten", style="Alt.TButton", width=30,
           command=lambda: run_in_thread(list_devices)).pack(pady=6)

ttk.Button(frame_middle, text="⚙️ EEPROM programmieren", style="Accent.TButton", width=30,
           command=lambda: run_in_thread(program_eeprom)).pack(pady=6)

ttk.Label(frame_middle, text="Optionale Flags für EEPROM:", font=("Segoe UI", 10, "bold"),
          background="#1e1e27", foreground="#e0e0e0").pack(pady=(10, 0))

# ----------------- tk.Checkbutton für statische Dark-Checkboxen -----------------
chk_usb = tk.Checkbutton(frame_middle, text="USB IDs aktivieren",
                         variable=enable_usb_ids_var,
                         bg="#1e1e27", fg="#e0e0e0",
                         selectcolor="#1e1e27", activebackground="#1e1e27",
                         font=("Segoe UI", 10))
chk_usb.pack(pady=2, anchor="w")

chk_hid = tk.Checkbutton(frame_middle, text="HID Bit aktivieren",
                         variable=enable_hid_bit_var,
                         bg="#1e1e27", fg="#e0e0e0",
                         selectcolor="#1e1e27", activebackground="#1e1e27",
                         font=("Segoe UI", 10))
chk_hid.pack(pady=2, anchor="w")

# -------------------------------------------------------
# Logfeld mit Scrollbar und Rahmen
# -------------------------------------------------------
log_frame_inner = tk.Frame(frame_log, bg="#121218", bd=2, relief="groove")
log_frame_inner.pack(fill="both", expand=True, padx=5, pady=5)

scroll = ttk.Scrollbar(log_frame_inner)
scroll.pack(side="right", fill="y")

log_text = tk.Text(
    log_frame_inner,
    height=16,
    bg="#121218",
    fg="#a0e8ff",
    insertbackground="white",
    font=("Consolas", 10),
    wrap="word",
    yscrollcommand=scroll.set,
    bd=2,
    relief="sunken"
)
scroll.config(command=log_text.yview)
log_text.pack(fill="both", expand=True, padx=3, pady=3)

log_text.insert("end", "🌙 Tool gestartet...\n")
log_text.config(state="disabled")

def log(msg, tag=None):
    log_text.config(state="normal")
    log_text.insert("end", msg + "\n", tag)
    log_text.see("end")
    log_text.config(state="disabled")

log_text.tag_config("success", foreground="#7CFC00")
log_text.tag_config("error", foreground="#ff6b6b")
log_text.tag_config("info", foreground="#00E5FF")

# -------------------------------------------------------
# Bottom Frame – Fortschritt & Status
# -------------------------------------------------------
progress = ttk.Progressbar(frame_bottom, orient="horizontal", mode="determinate",
                           length=720, variable=progress_value)
progress.pack(pady=8)
ttk.Label(frame_bottom, textvariable=status_var, foreground="#aaaaaa",
          background="#1e1e27").pack()
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

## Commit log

2025-09-25 readme 👍
2025-12-04 Upload conboard
    [GM340_conboard-B_Cu.gbr, GM340_conboard-B_Mask.gbr, GM340_conboard-B_Paste.gbr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]
2025-12-23 Some PCB updates
    [GM340_conboard-B_Cu.gbr, GM340_conboard-B_Mask.gbr, GM340_conboard-B_Paste.gbr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]
2026-01-27 Fix spelling and enhance description in README
    Corrected spelling of 'LED`s' to 'LEDs' and improved description.
2026-01-27 Update README with clarification on LED status display
2026-01-27 Update LED behavior description for 'UP' state
2026-01-27 Fix formatting in README for LED behavior table
2026-01-27 Fix formatting in README for LED status display
2026-01-27 Modify service activation commands in README
    Updated commands for enabling the service to use '&&' for chaining.
2026-07-16 Update README with fan installation details
    Added information about fan installation and specifications.
2026-07-16 Clarify fan control functionality in README
    Updated the description of the fan control functionality.
2026-07-21 Enhance status table with LED indicators and descriptions
    Updated the status table to include colored LED indicators for STAT1 and STAT2, and revised descriptions for clarity.
2026-07-21 Remove LED and signal definition sections
    Removed sections on LED meanings and signal definitions from the README.
2026-08-09 Correct output description in README
    Fix grammatical error in README about output switching.
